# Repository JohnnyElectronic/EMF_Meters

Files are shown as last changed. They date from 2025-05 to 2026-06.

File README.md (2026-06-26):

# EMF Meter Replicas - Supernatural TV Series

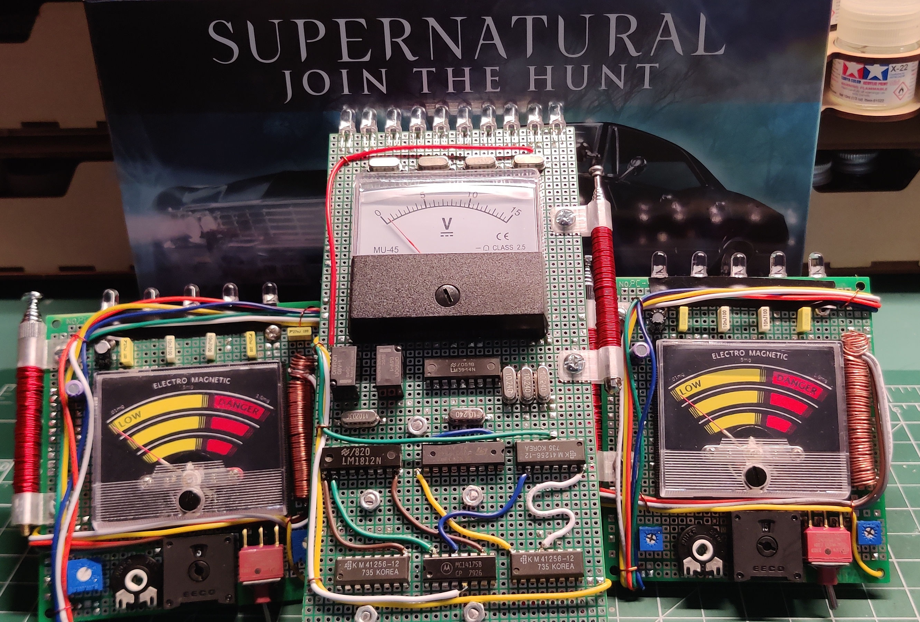
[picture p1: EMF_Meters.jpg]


## EMF Meters

- [Sam and Deans Classic EMF Meter](EMF_Meter_Replica/)
- [Olivia's 10 LED EMF Meter](10_LED_EMF_Meter_Replica/)

These meters are replicas of the ones seen in the Supernatural TV series.

* Sam and Deans Classic EMF Meter
This is the classic meter seen in many of the Supernatural episodes. It can be configured with 4 or 5 capacitors at the top, supports a variety of variable resistors and 9v or AA batteries.
This meter is a functional EMF meter and can detect Electric and Magnetic fields. It also has a test button to create EMF events any time.

* Olivia's 10 LED EMF Meter
This meter was only shown in one episode of the series but was a very standout meter. This is a prop only version with no EMF detection abilities. It was hand crafted on perfboard using point to point solder connections.
This is truly a one-of-a-kind meter. The meter has a test button similar to the other EMF meter for creating custom EMF events and also has 3 pre-programmed event sequences. These pre-programmed sequences can be added to or changed by reprogramming the ATtiny85 code.

> [!NOTE]
> [See My YouTube Channel for videos on assembly and operation of these meters](https://www.youtube.com/@Johnny_Electronic)

## Purchasing

[Visit my Etsy Store](https://johnnyelectronic.etsy.com)



## Licensing

This work is licensed under Creative Commons Attribution-ShareAlike 4.0 International. 
To view a copy of this license, visit [https://creativecommons.org/licenses/by-sa/4.0/](https://creativecommons.org/licenses/by-sa/4.0/)

Distributed as-is; no warranty is given.

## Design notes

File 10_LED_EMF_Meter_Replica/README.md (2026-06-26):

# 10 LED EMF Meter Replica - Olivia's Meter

- [Original perfboard (r1)](r1/)
- [New Updated Version on custom PCB (r2)](r2/)

Here is the documentation and support files for the Supernatural 10 LED EMF Meter Replica that Olivia used in season 4 episode 2. 
To assemble this circuit board you must be comfortable working with and soldering electronic parts.

This meter was only shown in one episode of the series but was a very standout meter. This is a prop only version with no EMF detection abilities. 
This is truly a unique meter. The meter has a test button similar to the other EMF meter for creating custom EMF events and also has 9 pre-programmed event sequences. 
These pre-programmed sequences can be added to or changed by reprogramming the ATtiny code.

An ATTiny is used to control the DFPlayer sound board and the analog meter deflection.
Programming is done through either a ICSP or UPDI programming interface depending on version. 

Check out the documents folder for more details.

## Journal Pages Now Available!
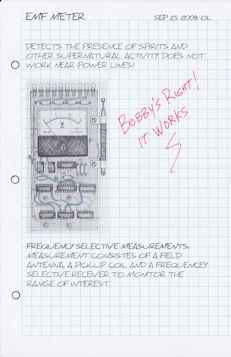
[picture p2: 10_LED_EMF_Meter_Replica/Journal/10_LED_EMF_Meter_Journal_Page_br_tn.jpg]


## Purchasing
[Visit my Etsy Store](https://johnnyelectronic.etsy.com)



## Directories

### Journal
-[Journal](Journal/)

### Version r1

-[Schematics](r1/schematics/)

-[Documents](r1/doc/)

-[Images](r1/img/)

-[Source code](r1/src/)

-[3D files](r1/3D/)

-[MP3 files](../EMF_Meter_Replica/mp3/)

### Version r2

-[Schematics](r2/schematics/)

-[Documents](r2/doc/)

-[Images](r2/img/)

-[Source code](r2/src/)

-[3D files](r1/3D/)

-[MP3 files](../EMF_Meter_Replica/mp3/)

### DFPlayer Files
-[DFPlayer](../DFPlayer/)

## Licensing

This work is licensed under Creative Commons Attribution-ShareAlike 4.0 International. 
To view a copy of this license, visit [https://creativecommons.org/licenses/by-sa/4.0/](https://creativecommons.org/licenses/by-sa/4.0/)

Distributed as-is; no warranty is given.

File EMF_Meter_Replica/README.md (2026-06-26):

# EMF Meter Replica - Supernatural TV Series



- [EMF Meter Replica (r1)](r1/)
- [EMF Meter Replica (r2) - Updated Version!](r2/)

Here is the documentation and support files for building and using the Supernatural EMF Meter Replica. 
To assemble this circuit board you must be comfortable working with and soldering electronic parts.
A full assembly and usage guide is available in the "doc" folder as well as a 2 part video series is 
available on YouTube.

## Technical Details

* Dimensions: 86 mm (3.46") x 95 mm (3.74") 
* Options for 9v or AA batteries
* 5 LEDS driven by an LM3914 (Jumper Option for DOT/BAR Mode)
* ATtiny85 controller
* DFPlayer module for audio
* Supports 3326,3362, or 3386 F and P series blue potentiometers
* Supports PT10 or PT15 black potentiometer
* Optional 5th yellow capacitor
* Uses a functional EECO switch to select the gain for the E-Field detector and can support a number of different EECO switches. Specifically, EECO 2700 series -02, -19, -31, -33, -41, -44 will work as is and others can be adapted to work. The PCB footprint supports 6 and 12 pin switches.
* Flexible wiring options.

This is a functional EMF meter that can detect both Electric and Magnetic fields. 
It can also be built as a simple prop by not populating the analog components. 
The meter was designed to replicate a variety of the meter configurations used in the TV series.

An ATTiny85 is used to control the DFPlayer sound board. 
Programming for the ATTiny85 can be accomplished using an In-Circuit Serial Programming (ICSP) port to program the part on the board. 
I also have available a soft touch programming cable for programming this part. 

Check out the documents folder for more details.

> [!NOTE]
> [See My YouTube Channel for examples on programming ATTiny parts using a softtouch cable](https://www.youtube.com/@Johnny_Electronic/playlists)

## Journal Pages Now Available!
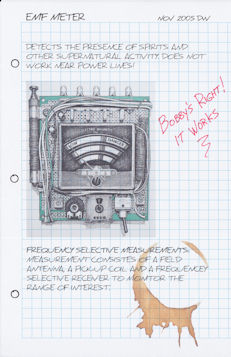
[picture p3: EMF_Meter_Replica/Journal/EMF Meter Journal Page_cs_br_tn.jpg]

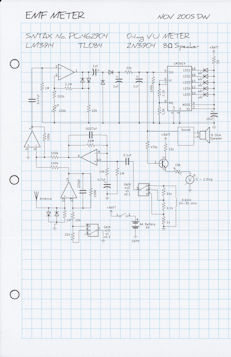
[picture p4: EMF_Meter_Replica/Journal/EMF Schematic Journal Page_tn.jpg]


## Purchasing
[Visit my Etsy Store](https://johnnyelectronic.etsy.com)



## Directories

### Journal Pages
-[Journal Pages](Journal/)

### Version r1

-[Schematics](r1/schematics/)

-[Documents](r1/doc/)

-[Images](r1/img/)

-[Source code](src/)

-[3D files](3D/)

-[MP3 files](mp3/)

### Version r2

-[Schematics](r2/schematics/)

-[Documents](r2/doc/)

-[Images](r2/img/)

-[Source code](src/)

-[3D files](3D/)

-[MP3 files](mp3/)

### DFPlayer Files
-[DFPlayer](../DFPlayer/)

## Licensing

This work is licensed under Creative Commons Attribution-ShareAlike 4.0 International. 
To view a copy of this license, visit [https://creativecommons.org/licenses/by-sa/4.0/](https://creativecommons.org/licenses/by-sa/4.0/)

Distributed as-is; no warranty is given.

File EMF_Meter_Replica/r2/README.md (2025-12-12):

# EMF Meter Replica (r2) - Updated Version!

**Blank PCB**

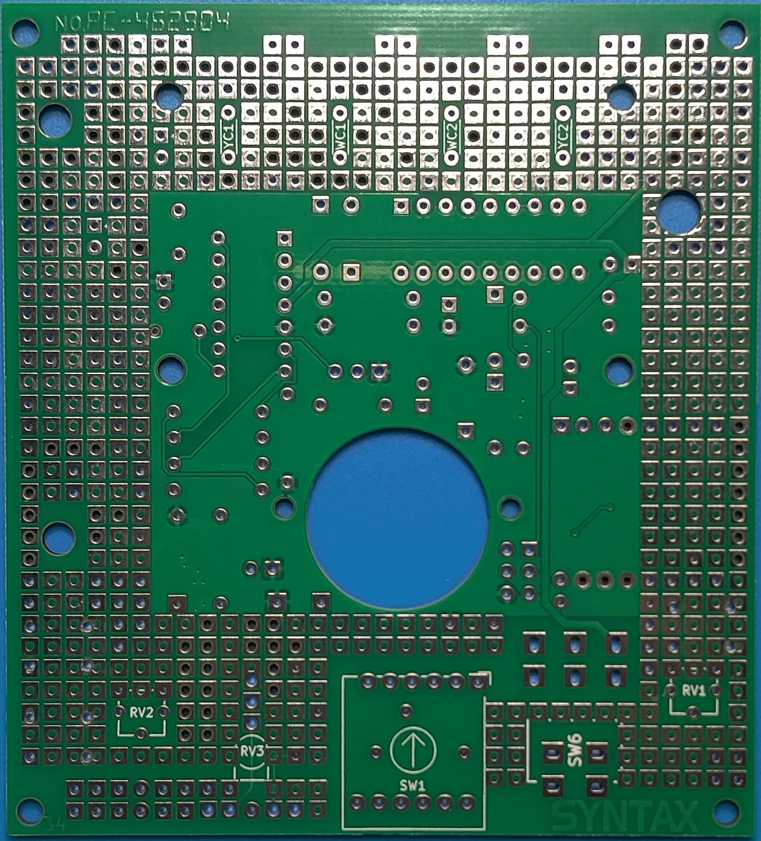
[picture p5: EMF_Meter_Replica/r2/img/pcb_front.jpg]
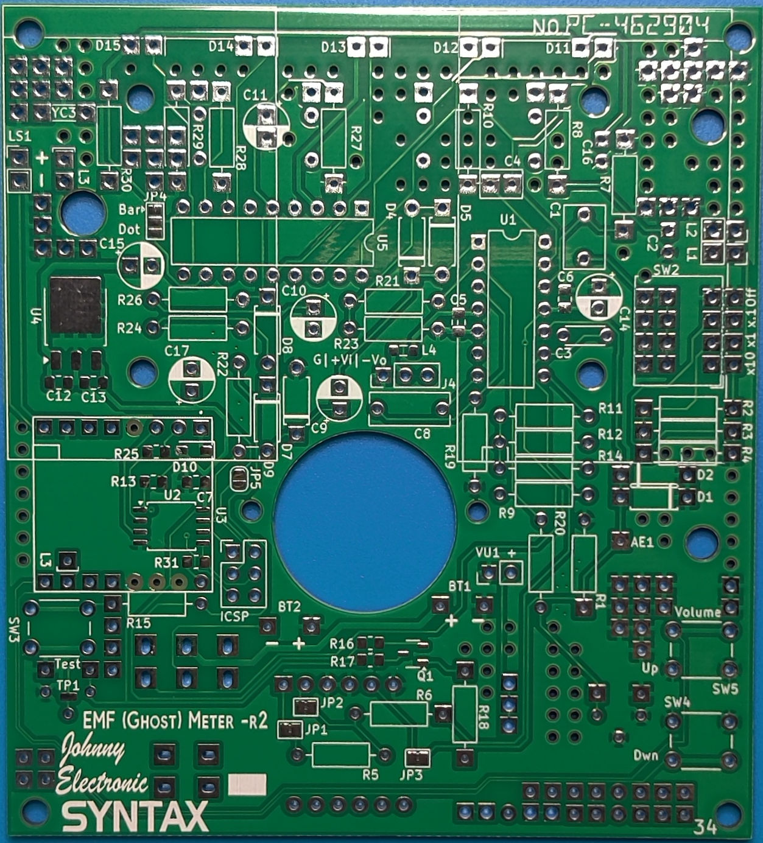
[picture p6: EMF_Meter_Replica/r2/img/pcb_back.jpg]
  

**Example of Assembled EMF Meter**

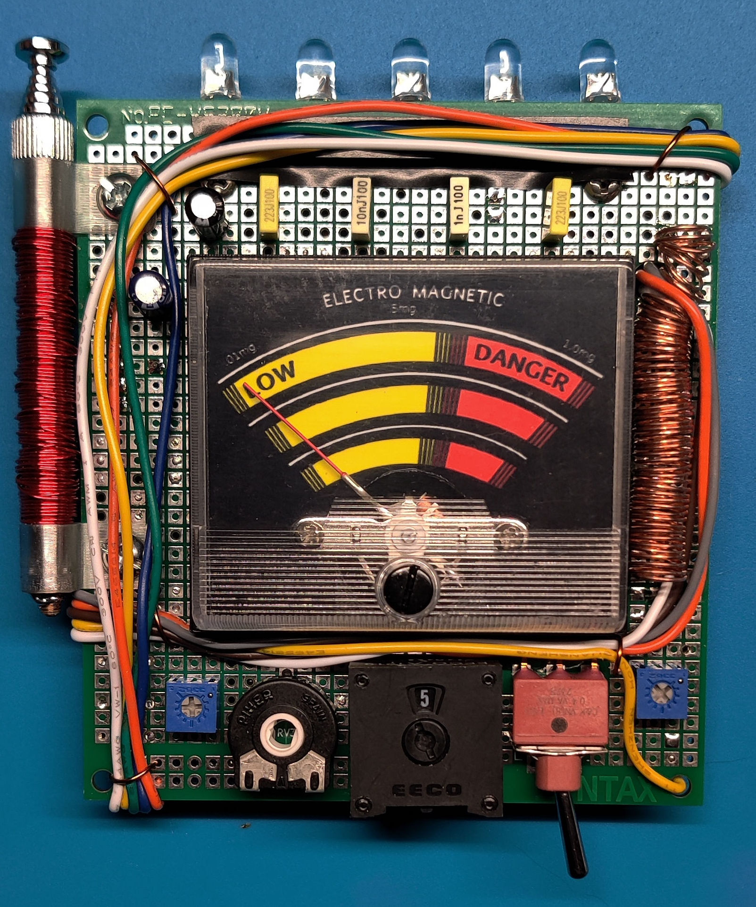
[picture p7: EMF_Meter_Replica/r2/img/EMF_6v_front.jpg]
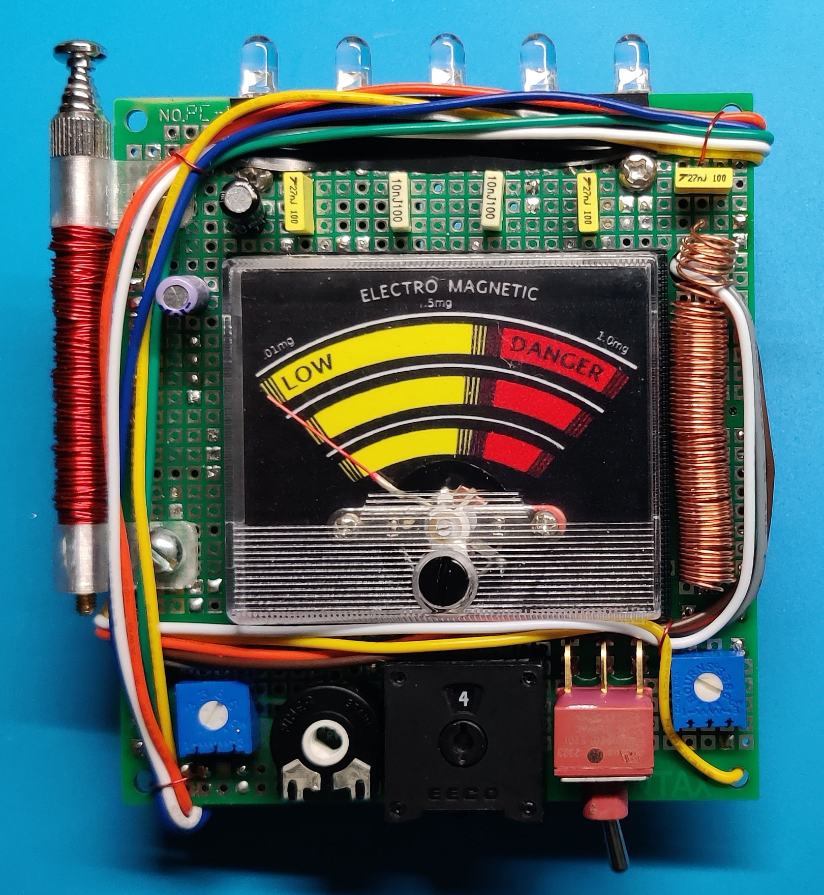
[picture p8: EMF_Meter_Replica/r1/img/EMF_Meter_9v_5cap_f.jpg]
  

Here is the documentation and support files for building and using the Supernatural EMF Meter Replica. 
To assemble this circuit board you must be comfortable working with and soldering electronic parts.
A full assembly and usage guide is available in the "doc" folder as well as a 2 part video series.

## Technical Details

* Dimensions: 86 mm (3.46") x 95 mm (3.74") 
* Options for 9v or AA batteries
* 5 LEDS driven by an LM3914 (Jumper Option for DOT/BAR Mode)
* ATtiny85 controller
* DFPlayer module for audio
* Supports 3326,3362, or 3386 F and P series blue potentiometers
* Supports PT10 or PT15 black potentiometer
* Optional 5th yellow capacitor
* Uses a functional EECO switch to select the gain for the E-Field detector and can support a number of different EECO switches. Specifically, EECO 2700 series -02, -19, -31, -33, -41, -44 will work as is and others can be adapted to work. The PCB footprint supports 6 and 12 pin switches.
* Flexible wiring options.

This is a functional EMF meter that can detect both Electric and Magnetic fields. 
It can also be built as a simple prop by not populating the analog components. 
The meter was designed to replicate a variety of the meter configurations used in the TV series.

An ATTiny85 is used to control the DFPlayer sound board. 
Programming for the ATTiny85 can also be accomplished using an In-Circuit Serial Programming (ICSP) port to program the mounted part on the board. 
I also have available a soft touch programming cable for programming this part. 

Check out the documents folder for more details.

> [!NOTE]
> [See My YouTube Channel for examples on programming ATTiny parts using a softtouch cable](https://www.youtube.com/@Johnny_Electronic/playlists)

## Purchasing
[Visit my Tindie Store](https://www.tindie.com/stores/johnnyelectronic/)



## Directories

-[Schematics](schematics/)

-[Documents](doc/)

-[Images](img/)

-[Source code](../src/)

-[3D files](../3D/)

-[MP3 files](../mp3/)

## Licensing

This work is licensed under Creative Commons Attribution-ShareAlike 4.0 International. 
To view a copy of this license, visit [https://creativecommons.org/licenses/by-sa/4.0/](https://creativecommons.org/licenses/by-sa/4.0/)

Distributed as-is; no warranty is given.

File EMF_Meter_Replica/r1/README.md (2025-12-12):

# EMF Meter Replica (r1) - Discontinued

**Blank PCB**

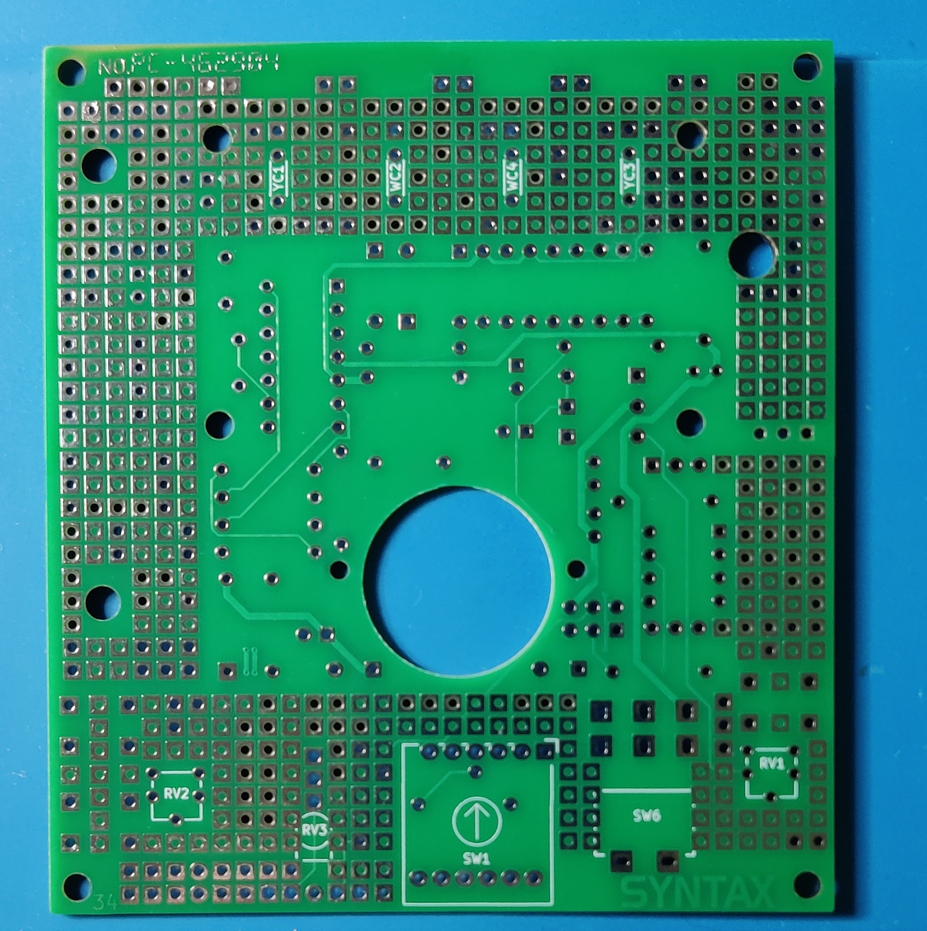
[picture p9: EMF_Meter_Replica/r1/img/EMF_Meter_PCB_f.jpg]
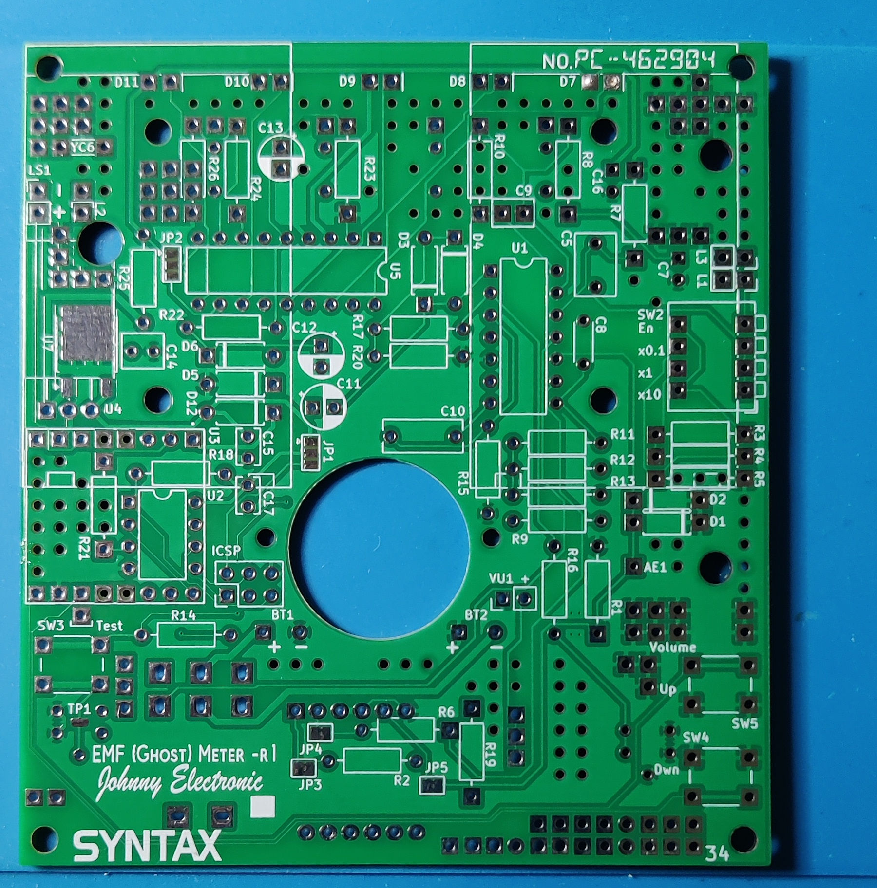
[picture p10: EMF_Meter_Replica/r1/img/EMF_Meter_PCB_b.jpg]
  

**Example of Assembled EMF Meter**

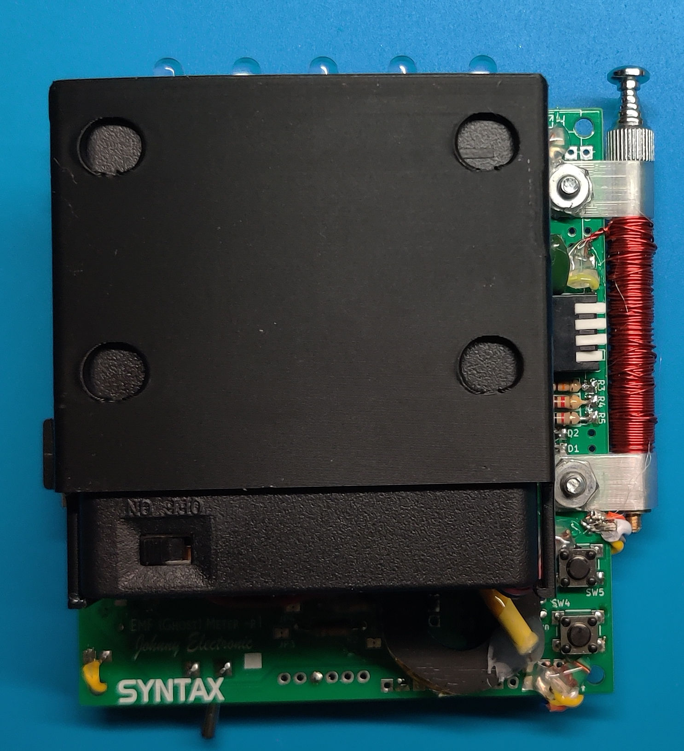
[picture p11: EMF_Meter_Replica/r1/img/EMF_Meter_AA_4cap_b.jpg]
  

Here is the documentation and support files for building and using the Supernatural EMF Meter Replica. 
To assemble this circuit board you must be comfortable working with and soldering electronic parts.
A full assembly and usage guide is available in the "doc" folder as well as a 2 part video series.

## Technical Details

* Dimensions: 86 mm (3.46") x 95 mm (3.74") 
* Options for 9v or AA batteries
* 5 LEDS driven by an LM3914 (Jumper Option for DOT/BAR Mode)
* ATtiny85 controller
* DFPlayer module for audio
* Supports 3326,3362, or 3386 F and P series blue potentiometers
* Supports PT10 or PT15 black potentiometer
* Optional 5th yellow capacitor
* Uses a functional EECO switch to select the gain for the E-Field detector and can support a number of different EECO switches. Specifically, EECO 2700 series -02, -19, -31, -33, -41, -44 will work as is and others can be adapted to work. The PCB footprint supports 6 and 12 pin switches.
* Flexible wiring options.

This is a functional EMF meter that can detect both Electric and Magnetic fields. 
It can also be built as a simple prop by not populating the analog components. 
The meter was designed to replicate a variety of the meter configurations used in the TV series.

An ATTiny85 is used to control the DFPlayer sound board. 
Programming for the ATTiny85 can be done before mounting and can also be accomplished using an In-Circuit Serial Programming (ICSP) port to program the mounted part on the board. 
There is a jumper option (JP1) to select either the main board power or to use the ICSP port for programming power. I also have available a soft touch programming cable for programming this part. 

Check out the documents folder for more details.

> [!NOTE]
> [See My YouTube Channel for examples on programming ATTiny parts using a softtouch cable](https://www.youtube.com/@Johnny_Electronic/playlists)

## Purchasing
[Visit my Tindie Store](https://www.tindie.com/stores/johnnyelectronic/)



## Directories

-[Schematics](schematics/)

-[Documents](doc/)

-[Images](img/)

-[Source code](../src/)

-[3D files](../3D/)

-[MP3 files](../mp3/)

## Licensing

This work is licensed under Creative Commons Attribution-ShareAlike 4.0 International. 
To view a copy of this license, visit [https://creativecommons.org/licenses/by-sa/4.0/](https://creativecommons.org/licenses/by-sa/4.0/)

Distributed as-is; no warranty is given.

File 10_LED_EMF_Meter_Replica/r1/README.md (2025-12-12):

# 10 LED EMF Meter Replica - Olivia's Meter (r1)

**Blank PCB**

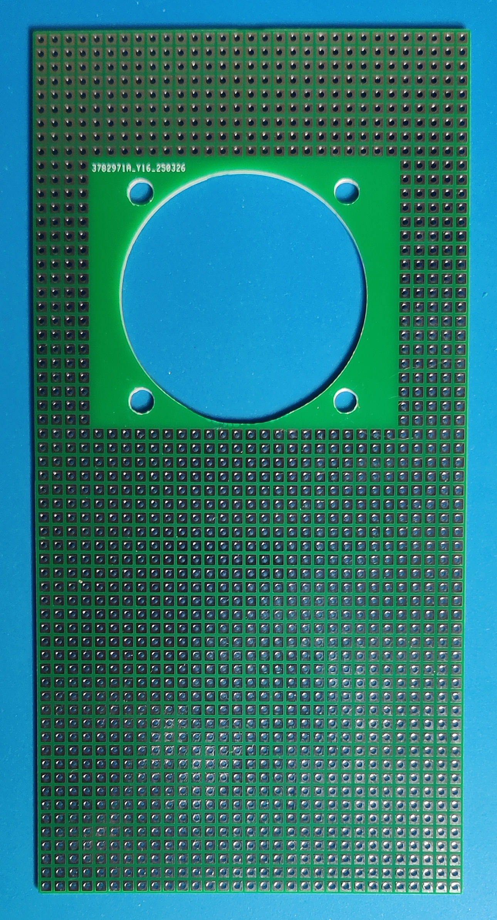
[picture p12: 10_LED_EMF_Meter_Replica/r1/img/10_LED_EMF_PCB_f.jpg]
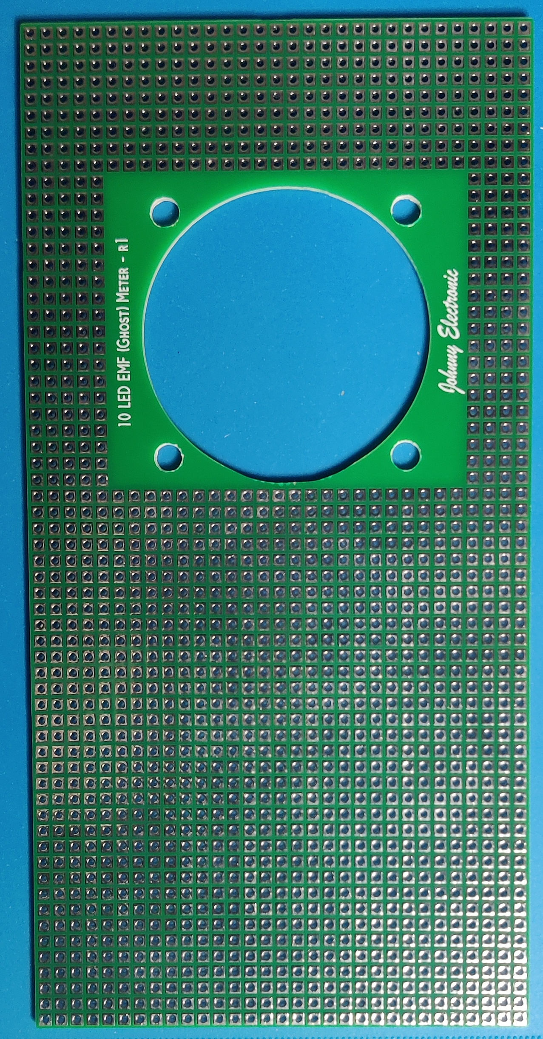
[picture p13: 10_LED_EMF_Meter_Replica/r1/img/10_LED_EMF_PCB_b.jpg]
  

**Example of Assembled EMF Meter**

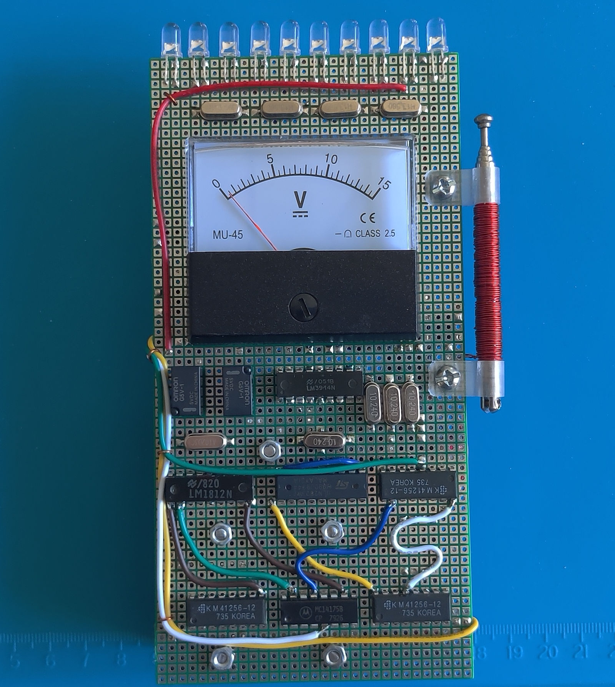
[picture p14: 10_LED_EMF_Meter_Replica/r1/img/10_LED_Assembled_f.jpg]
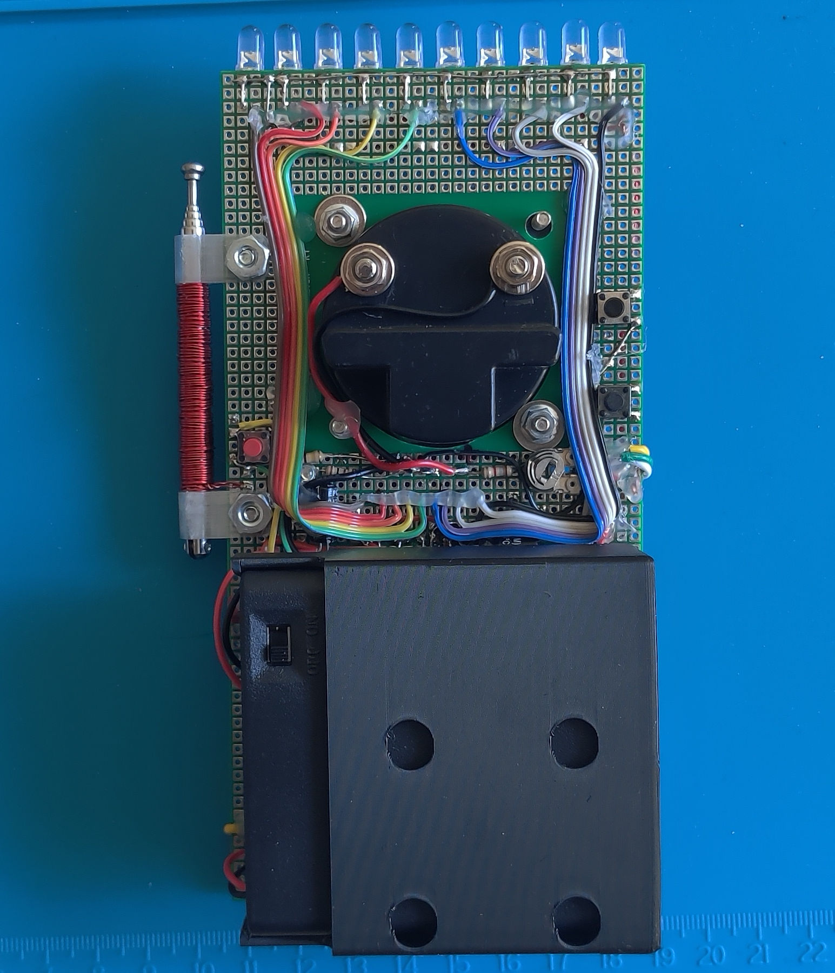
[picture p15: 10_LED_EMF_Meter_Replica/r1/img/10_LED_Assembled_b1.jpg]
  

Here is the documentation and support files for the Supernatural 10 LED EMF Meter Replica that Olivia used in season 4 episode 2. 
To assemble this circuit board you must be comfortable working with and soldering electronic parts.
A partial build video is available on my YouTube site. This meter is built on a perfboard so assembly is at the discreation of the hunter (Ah, builder).
A schematic is available along with a Bill of Materials (BOM). 

## Technical Details

* Dimensions: 79 mm x 158 mm 
* Uses 4 AA batteries
* 10 LEDS driven by an LM3914 (Set to BAR mode)
* ATtiny85 controller
* DFPlayer module for audio

This meter was only shown in one episode of the series but was a very standout meter. This is a prop only version with no EMF detection abilities. It was hand crafted on perfboard using point to point solder connections.
This is truly a one-of-a-kind meter. The meter has a test button similar to the other EMF meter for creating custom EMF events and also has 3 pre-programmed event sequences. 
These pre-programmed sequences can be added to or changed by reprogramming the ATtiny85 code.

An ATTiny85 is used to control the DFPlayer sound board and the analog meter deflection. 
The ATTiny85 is socketed and can be reprogrammed if needed. 

Check out the documents folder for more details.

## Purchasing
[Visit my Tindie Store](https://www.tindie.com/stores/johnnyelectronic/)



## Directories

-[Schematics](schematics/)

-[Documents](doc/)

-[Images](img/)

-[Source code](src/)

-[3D files](3D/)

## Licensing

This work is licensed under Creative Commons Attribution-ShareAlike 4.0 International. 
To view a copy of this license, visit [https://creativecommons.org/licenses/by-sa/4.0/](https://creativecommons.org/licenses/by-sa/4.0/)

Distributed as-is; no warranty is given.

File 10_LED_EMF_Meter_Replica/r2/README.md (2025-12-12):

# 10 LED EMF Meter Replica - Olivia's Meter (r2)

### Updated version ###

**Blank PCB**

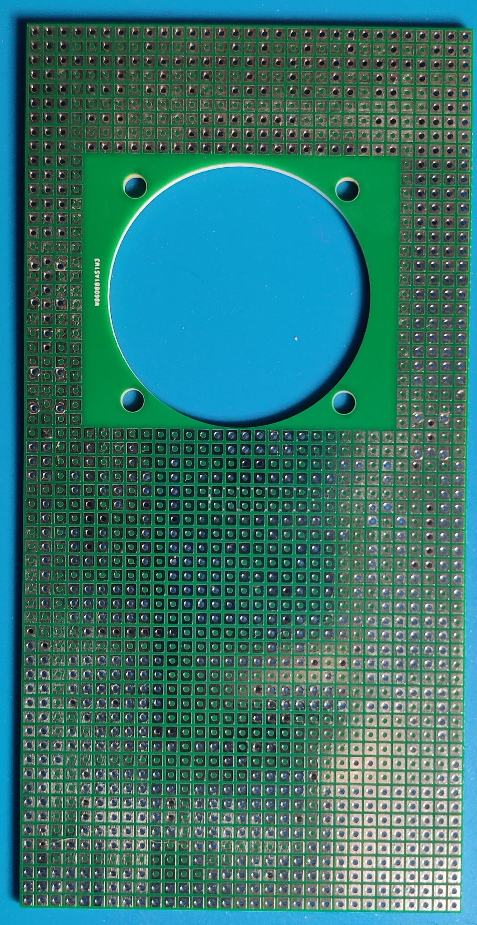
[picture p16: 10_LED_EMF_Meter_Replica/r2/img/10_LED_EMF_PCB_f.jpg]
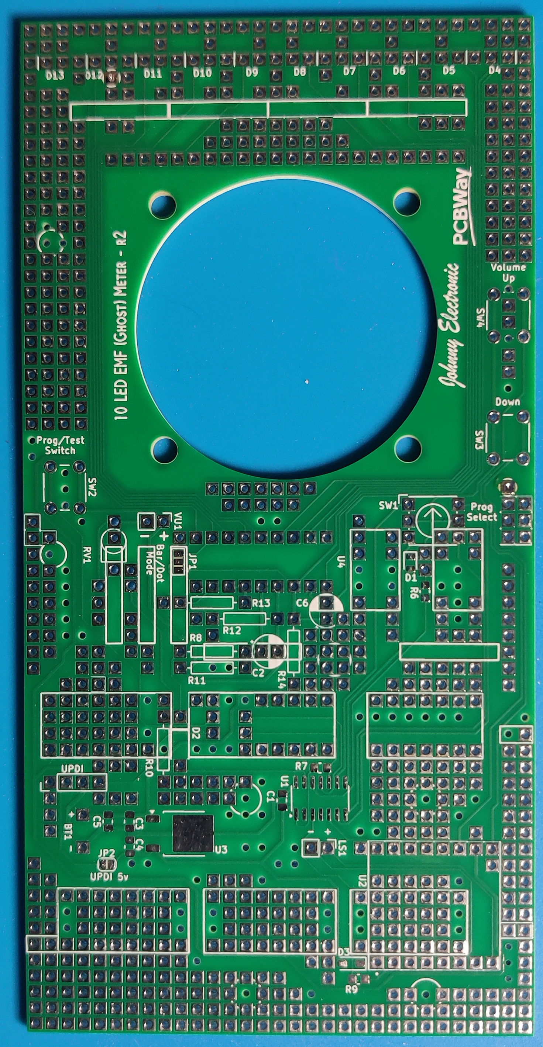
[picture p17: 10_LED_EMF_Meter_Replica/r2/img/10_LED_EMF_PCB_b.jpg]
  

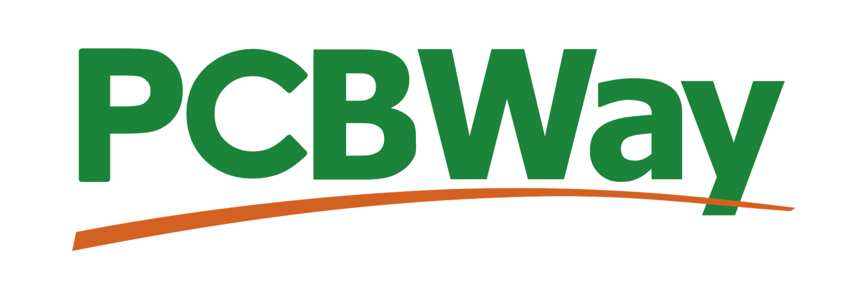
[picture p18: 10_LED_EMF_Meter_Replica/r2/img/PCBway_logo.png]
**PCB Made By**

**Example of Assembled EMF Meter**

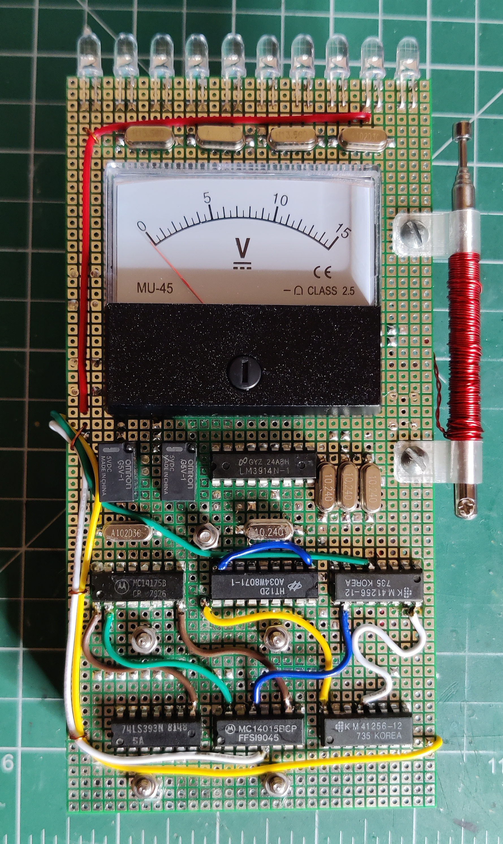
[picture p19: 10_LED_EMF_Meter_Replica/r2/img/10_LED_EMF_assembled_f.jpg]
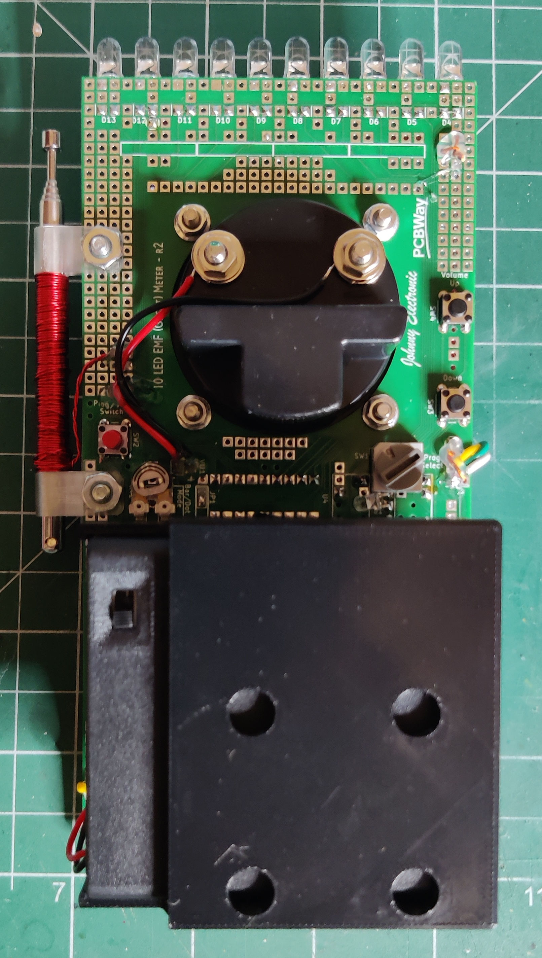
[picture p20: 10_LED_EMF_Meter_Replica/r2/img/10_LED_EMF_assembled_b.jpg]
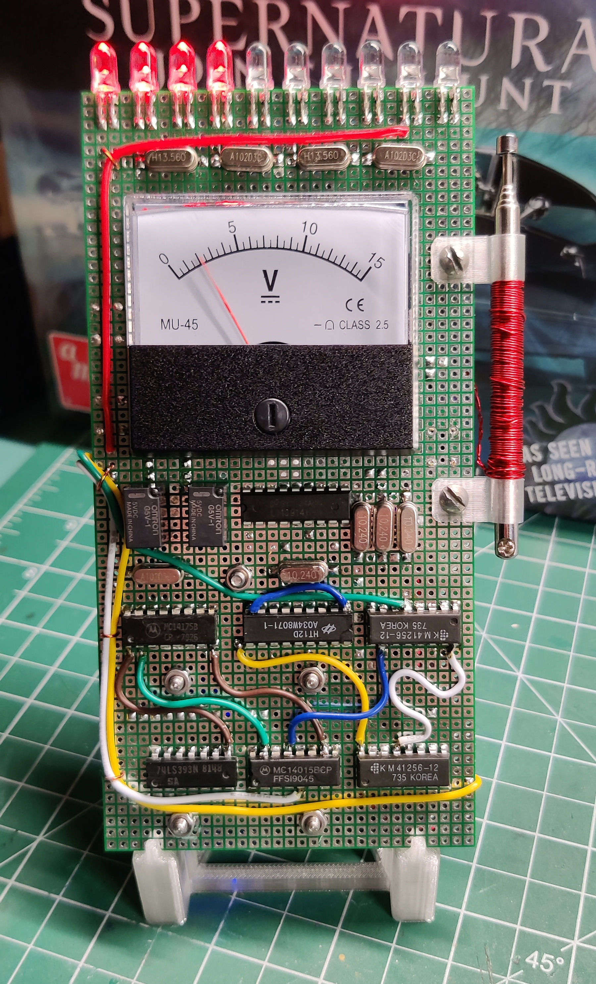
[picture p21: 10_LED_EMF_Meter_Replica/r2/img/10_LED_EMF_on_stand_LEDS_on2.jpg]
    

Here is the documentation and support files for the Supernatural 10 LED EMF Meter Replica that Olivia used in season 4 episode 2. 
To assemble this circuit board you must be comfortable working with and soldering electronic parts.
A build video is available on my YouTube site. This meter uses through hole and surface mounted parts. The smallest SMT will be a 0805 package.
A schematic is available along with a Bill of Materials (BOM). 

## Technical Details

* Dimensions: 79 mm x 158 mm 
* Uses 4 AA batteries
* 10 LEDS driven by an LM3914N (Set to BAR mode)
* ATTiny1604 controller
* DFPlayer module for audio
* 9 Pre-Programmed EMF sequences

This meter was only shown in one episode of the series but was a very standout meter. This is a prop only version with no EMF detection abilities. 
This is truly a unique meter. The meter has a test button similar to the other EMF meter for creating custom EMF events and also has 9 pre-programmed event sequences.
The pre-programmed sequences can be selected using a rotary switch and then a quick press of the Program/Test button to start the sequence. Using the 0 position each button
press will rotate to the next programmed sequence. These pre-programmed sequences can be added to or changed by reprogramming the ATtiny code.

An ATTiny1604 is used to control the DFPlayer sound board and the VU/LED meter deflection. 
The ATTiny1604 can be reprogrammed using the UPDI port. 

Check out the documents folder for more details.

## Purchasing
[Visit my Tindie Store](https://www.tindie.com/stores/johnnyelectronic/)



## Directories

-[Schematics](schematics/)

-[Documents](doc/)

-[Images](img/)

-[Source code](src/)

-[3D files](../r1/3D/)

-[MP3 files](../../EMF_Meter_Replica/mp3/)

## Licensing

This work is licensed under Creative Commons Attribution-ShareAlike 4.0 International. 
To view a copy of this license, visit [https://creativecommons.org/licenses/by-sa/4.0/](https://creativecommons.org/licenses/by-sa/4.0/)

Distributed as-is; no warranty is given.

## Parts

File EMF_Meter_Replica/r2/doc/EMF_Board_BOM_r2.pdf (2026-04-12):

### Functional EMF Meter -r2 BOM

Reference | Description | Value | Quantity | Dat sheet or Part Link

AE1

Antenna 3” – 8 5/8”, 5 Segment, Dia. 5mm (.198”)
or ATT 5000 Cordless phone antenna | Ant 3", 5mm | 0

AliExpress. 17/25cm 5 Section Metal Full-Channel Am Fm Radio Antenna Telescopic Antenna Rotating Antenna Aerial M2.5 https://www.aliexpress.us/item/3256806492066394.html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 21US%212927003445%21X&curPageLogUid=uOVDvnEgydBL&utparam-url=scene%3Asearch%7Cquery_from%3A

eBay for the ATT

+ Red Enamel 26 AWG Wire Wrap
AE1 Option | ATT 5000 Cordless phone antenna | 6mm Dia 3" antenna | 1 eBay as low as $3.5 each
BT1 | 6v Battery Pack - 6V Option | 4 AA Batteries | 1 For 6V supply BT1, BT1 3D, Buck1 are required.
| | | Aliexpress: https://www.aliexpress.us/w/wholesale-4-Slots-AA-Battery-Holder.html?spm=a2g0o.productlist.search.0
BT1 3D | 6v Battery Pack Mount, 3D printed | AA 3D Holder | 1 For 6V supply BT1, 3D printed batterypack holder. AAx4 battery pack required
BUCK1 | 6V buck converter | DD0315NA | 1 https://www.aliexpress.us/item/2251832636713190.html
BT1,BT2 | 9v Battery Clip and Holder - 9V Option | 3D Printed | 0 For 9V supply BT1, BT2, 9V batteries with clips + 3D printed 9V batery Holder, 2 each required
YC1,YC2,YC3 | Yellow .022uf Cosmetic Capacitor (22n) | Y .022uf Cosmetic | 3 All Electronics, Yellow Metallized polyester film radial capacitors. 22n or 22 nf desired. .022uf
| | | AliExpress
WC2,WC2 | White .001uf Cosmetic Capacitor (10n) | W .001uf Cosmetic | 2 All Electronics, White Metallized polyester film radial capacitors. Marking 10n desired, .001uf
| | | AliExpress
C1 | Mylar Capacitor | 0.1uf | 1 MLCC substitute or Jameco / AliExpress for Mylar
C2 | Electrolytic Capacitor - Blue Sleeve | 4.7uf | 1 Mouser/Digikey
C3 | Ceramic Disk Capacitor | 220pf | 1 Mouser/Digikey
C4 | Mylar/MLCC Capacitor | .0027uf | 1 AliExpress/Mouser
C8 | Mylar/MLCC Capacitor | .047uf | 1 Jameco, AliExpress, Mouser/Digikey
C9,C10,C11 | Electrolytic Capacitor | 1uf | 3 Mouser/Digikey
C17 | Electrolytic Capacitor - Optional based on 5v regulator | 1uf | 1 Mouser/Digikey
C12,C13 | Ceramic Capacitor-0805 SMD, Based on Regulator | 0.1-0.33uf | 1 Mouser/Digikey, 0805 Package
C5,C6,C7 | Ceramic Capacitor-0805 SMD | 0.1uf | 3 Mouser/Digikey, 0805 Package
C14 | Electrolytic Capacitor - Optional, used with -6v BUCK1 | 220uf | 1 Mouser/Digikey, 220uf/10v
C15 | Electrolytic Capacitor | 10uf | 1 Mouser/Digikey
C16 | Electrolytic Capacitor - Black Sleeve | 10uf | 1 Mouser/Digikey
D1, D2, D4, D5, D7, D8, D9 | Signal Diode | 1N914 | 7 Mouser/Digikey
D11, D12, D13, D14, D15 | Red LED | Ultra Bright Red, 5MM | 5 Mouser, Lighthouse LED, AliExpress
D10 | Rectifier Diode, SMD | SL1A | 1 IN4001 equivalent, SL1A, Any source, SMD, SOD-123 package
L1 | EMF Pickup coil | 3D Printed | 1 32 gauge. 36 AWG Preferred 32g 0.11 per ft @ 120'
L2 | Cosmetic Antenna Coil Left Side, Optional EMF connection | Hand Made | 1 26 AWG red enameled, two layer wrap around telescopic antenna
L3 | Cosmetic Coil Right Side | Hand Made | 1 22AWG 0.6438mm 0.0253”, Copper Wire 0.65mm
L4 | 33uH Inductor, SMD 0805 | 33uH | 1 Mouser/Digikey, 33uH 0805 Package
LS1 | Speaker 20x30x4.6mm, 8 ohm, 1.5 Watt, Oval | 20x30mm 1-2Watt | 1 AliExpress. https://www.aliexpress.us/w/wholesale-Speaker-20x30mm.html?spm=a2g0o.productlist.search.0
Q1 | 2N3904/CMPT3019 or Equiv, SMD SOT-23 | CMPT3019 | 1 Mouser/Digikey
R1, R19, R7 | 1/4w Resistor | 1M | 3 Any source
R26, R5 | 1/4w Resistor | 22k | 2 Any source
R2 | 1/4w Resistor | 91k | 1 Any source
R3 | 1/4w Resistor | 9.1k | 1 Any source
R4 | 1/4w Resistor | 1k | 1 Any source
R23, R6, R8 | 1/4w Resistor | 10k | 3 Any source
R13 | 1/8w SMD Resistor, 0805 | 10k | 1 Any source
R11, R12, R14, R20, R27, R9 1/4w Resistor | 100k | 6 Any source
R10 | 1/4w Resistor | 10M | 1 Any source
R15 | 1/4w Resistor | 100 | 1 Any source
R16 | 1/8w SMD Resistor, 0805 | 470k | 1 Any source
R22 | 1/4w Resistor | 3.3M | 1 Any source
R21 | 1/4w Resistor | 2.2M | 1 Any source
R17 | 1/8w SMD Resistor, 0805 | 15k | 1 Any source
R18 | 1/4w Resistor | 7.5k | 1 Any source
R24 | 1/4w Resistor | 47k | 1 Any source
R25, R31 | 1/8w SMD Resistor, 0805 | 1.8k | 2 Any source
R28 | 1/4w Resistor | 1.2k | 1 Any source
R30 | 1/4w Resistor | 33 | 1 Any source
R29 | 1/4w Resistor | 1.5k | 1 Any source
RV1,RV2 | Variable resistor. 3326/3362/3386 F or P series | 100k | 2 Mouser Electronics, https://www.mouser.com/ProductDetail/Bourns/3386H-1-104LF?qs=m2uG%2FFdTAPVxro77x9HS0w%3D%3D
| | | Jameco https://www.jameco.com/z/3386P-1-104LF-JVP-Jameco-ValuePro-1-2-Watt-3-8-Square-Trimming-Potentiometer-100k-Ohm_43027.html ($0.99)
RV3 | 1k/5k ohm, Variable resistor (PT15 Series) | 5k | 1 PT15NV02-502A
| | | Included with VU meter or Jameco for PT15 Black Pot
SW1 | SW_Coded_EECO_2700 -31/33 | EECO 276133M | 1 eBay. A Variety of switches are supported.
SW2 | SW_DIP_x04, Piano or Rotary S-2151 | SW_DIP_x04 | 1 Digikey or Mouser, https://www.mouser.com/ProductDetail/CTS-Electronic-Components/195-4MS?qs=hDoPxpGr7ldwh3tetBscOg%3D%3D
| | | https://www.mouser.com/ProductDetail/Nidec-Components/S-2151?qs=XeJtXLiO41Q6vTgIJbo%2FGA%3D%3D
SW3,SW4,SW5 | SW_Push. 6x6x5mm SPST | Tactile Switches,6X6 | 3 Mouser, AliExpress

SW6

SW_SPDT AA Supply E101SD1ABE $16.62

| SW_DPDT 9v Supply E201MD1AV2BE $12.32-$15.46 | Toggle Switch | 1 Digikey/Mouser, C&K E201MD1AQE ($15.46) or E-Switch 100DP1T1B1M6QE ($4.35)
| | | https://www.mouser.com/ProductDetail/CK/E201MD1AQE?qs=c89up6qpALNEJs%2FyQ1km0A%3D%3D
| | | https://www.mouser.com/ProductDetail/E-Switch/100DP1T1B1M6QE?qs=wUXugUrL1qxY%252BYjsepFRcA%3D%3D
| | | https://www.mouser.com/ProductDetail/CK/E101SD1ABE?qs=V27O%2FkrGudytwoweDEvTYA%3D%3D
| | | 7mm MTS-202C3 AliExpress (Chrome casing $1.18)
U1 | TL084ACN | TL084 | 1 Mouser/Digikey
U2 | ATtiny85-20U, SOIC8 SMD | ATtiny85-20U | 1 Mouser/Digikey
U3 | DF Player PCB | DFR0299 | 1 AliExpress DFPlayer Mini, MP3-TF-16P (JL chip set, Blue LED Best. DFRobot works but some audio amp clicks $7-9)
U4 | 5v regulator (LDO), DPAK, SMD | TC1262-5 | 1 LF50CDT Regulator Minimum 500ma output. Mouser, w/ 9v source
| | | TC1262-5.0 Regulator LDO 500ma min, AA source
U5 | LM3914N | LM3914N | 1 AliExpress

VU1

Meter Element
Decibel Measurement on AC Voltage Range Analog Multimeter Tester for ACDC 1000V500m A/Voltmeter Ammeter Ohmmeter
Meter Volt
| Requires a 3D printed base | MF-110A | 1 AliExpress, https://www.aliexpress.us/w/wholesale-MF%2525252d110.html?spm=a2g0o.detail.search.0 (https://www.aliexpress.us/item/3256807924391371.html)
VU1_BASE | 3D Printed Base for MF-110 Meter element | | 1 Requires screws from MF-110A meter
Display Stand | 3D Printed, transparent | | 1
P-Clip | 6mm 3D printed, transparent | | 2 ATT antenna uses 6mm, Genric 3" antenna uses 5mm
MS-M3 | Mechanical screw, Battery Holder | M3 x 6mm | 8 AliExpress
MS-8 | Mechanical Threaded Standoff, Battery Holder | M3-10mm | 4 AliExpress
Misc Colored wire | Various wire routes, cosmetic only | 24 AWG | 1 Jameco, https://www.jameco.com/z/UL-1007-10CS-Jameco-ValuePro-24-AWG-10-Color-Stranded-Wire-Kit-Assortment_2187876.html
SD_CARD | Mico SD Card 1/4GB | 1 or 4GB | 1
EMF r2 PCB | PCB | | 1

### Approximate part cost $80.00

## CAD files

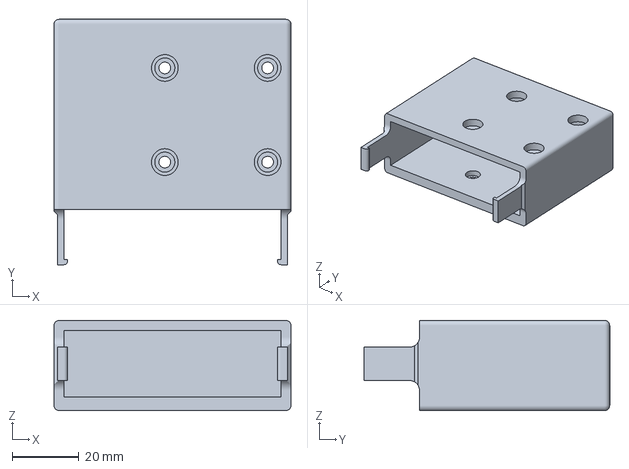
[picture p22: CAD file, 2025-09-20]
10_LED_EMF_Meter_Replica/r1/3D/AA_Battery_Pack_Holder_10_LED.3mf
71.0 x 73.6 x 27.0 mm

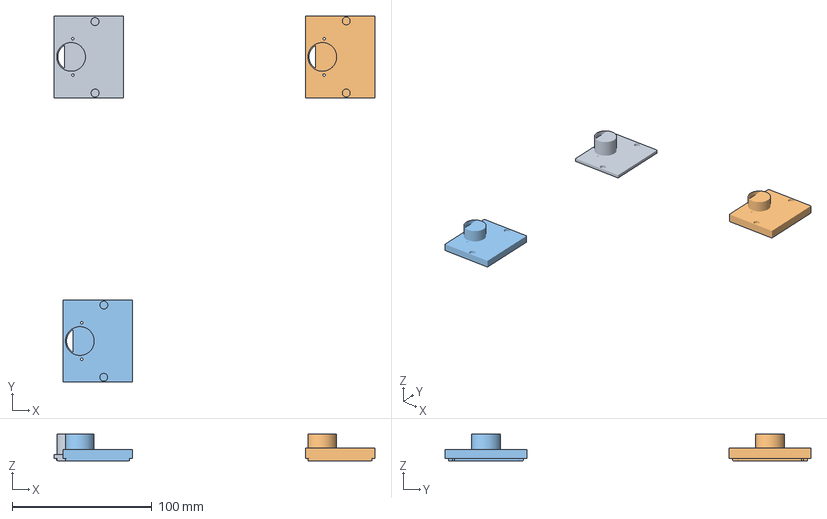
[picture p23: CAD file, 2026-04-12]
EMF_Meter_Replica/3D/EMF_Meter_Base_all versions.3mf
229.8 x 262.3 x 19.2 mm
Meter Base-7.6mm
Meter Base-6.6mm

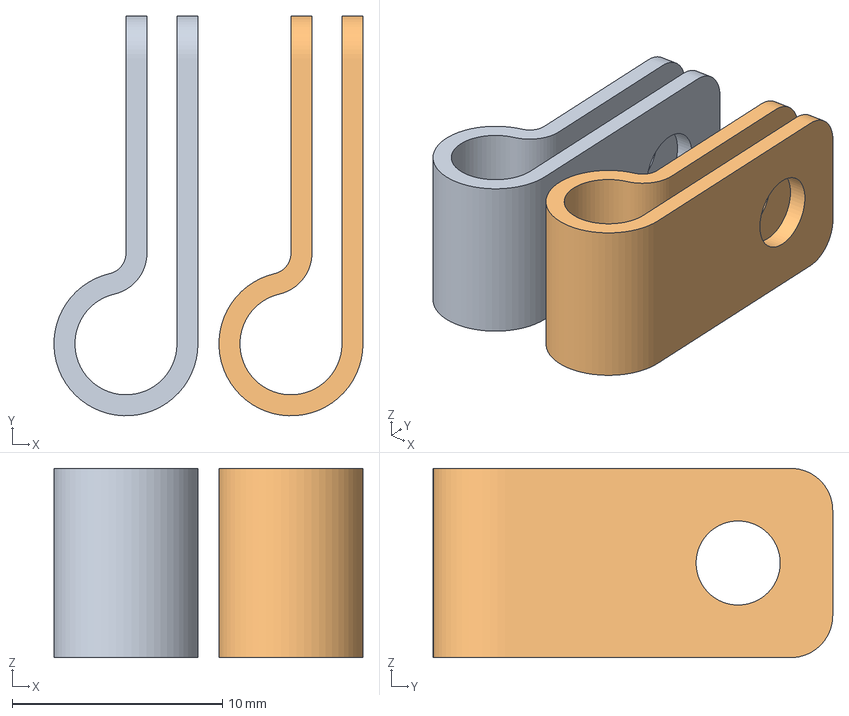
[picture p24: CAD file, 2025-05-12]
10_LED_EMF_Meter_Replica/r1/3D/EMF_P_Clip_5mm_dia.3mf
14.7 x 19.0 x 9.00 mm
P Clip x 2

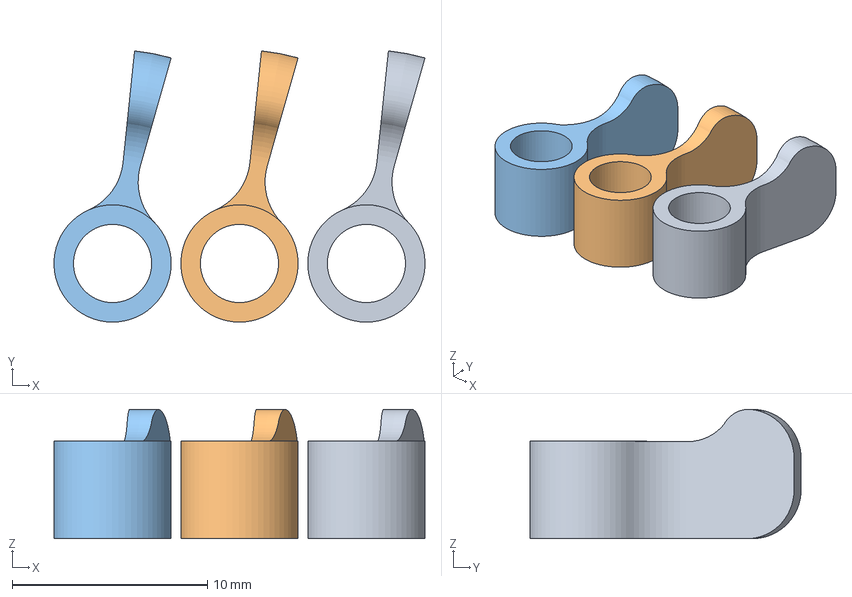
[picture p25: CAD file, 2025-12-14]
EMF_Meter_Replica/3D/Rotary Switch Lever.3mf
19.0 x 13.9 x 6.62 mm
Lever x 3

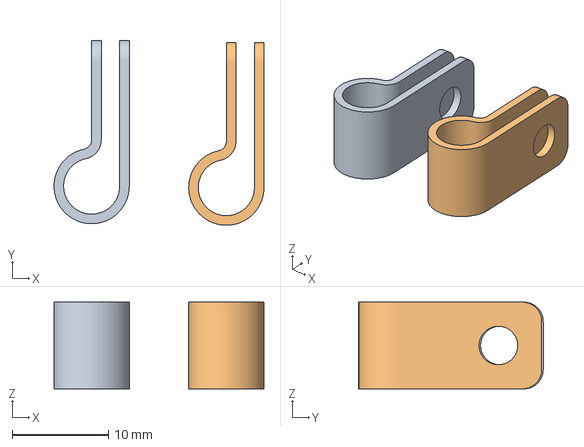
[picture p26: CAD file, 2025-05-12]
10_LED_EMF_Meter_Replica/r1/3D/EMF_P_Clip_6mm_dia.3mf
21.8 x 19.2 x 9.00 mm
P Clip x 2

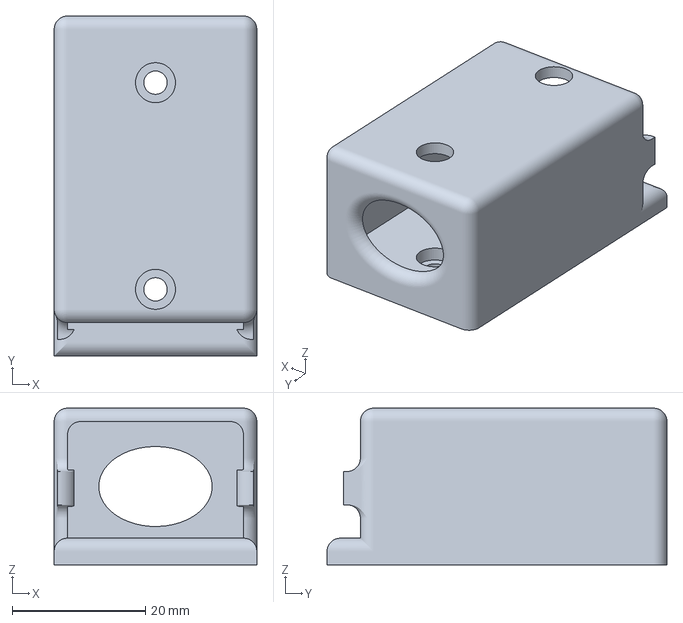
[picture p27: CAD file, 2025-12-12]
EMF_Meter_Replica/3D/9v_Battery_Holder.3mf
30.4 x 51.0 x 23.5 mm

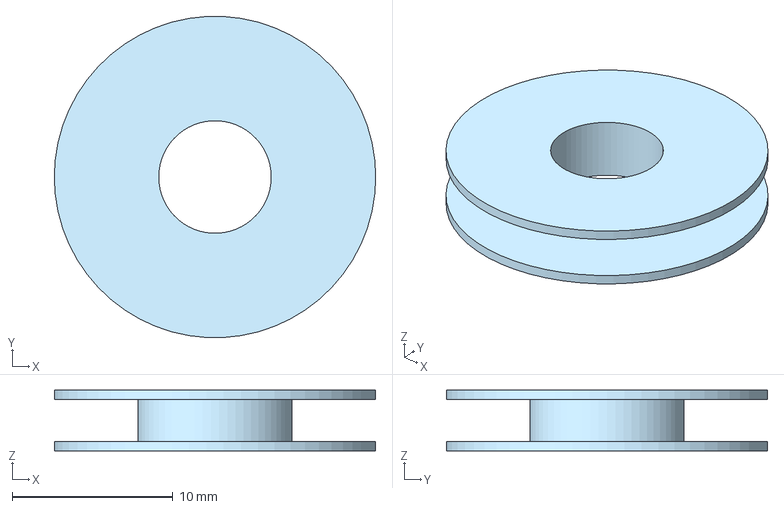
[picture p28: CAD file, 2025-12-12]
EMF_Meter_Replica/3D/EMF_Coil_Form_20mm.3mf
20.0 x 20.0 x 3.79 mm

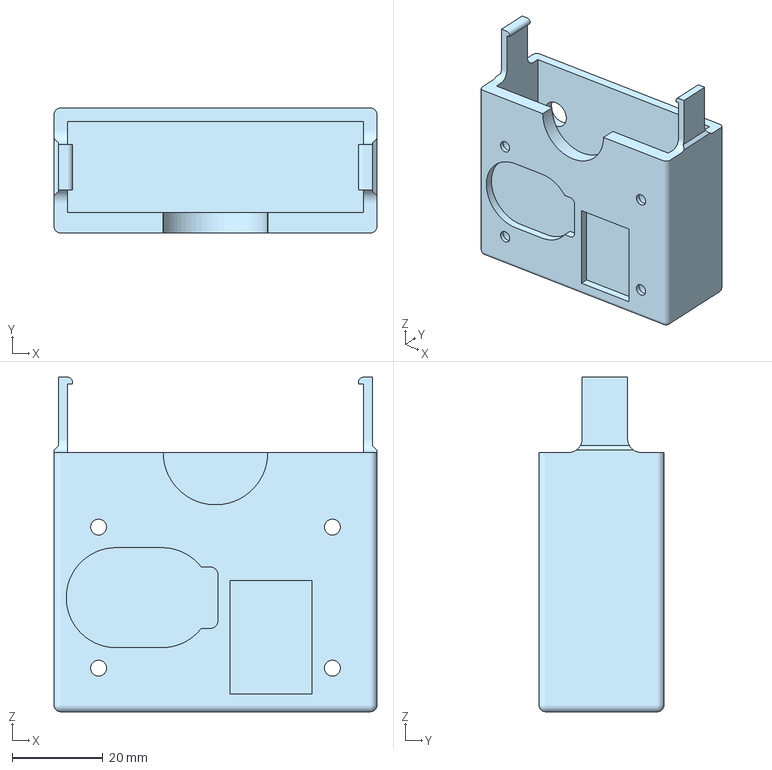
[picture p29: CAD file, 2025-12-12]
EMF_Meter_Replica/3D/AA_Bat_Holder_EMF_r2.3mf
71.0 x 27.5 x 73.6 mm

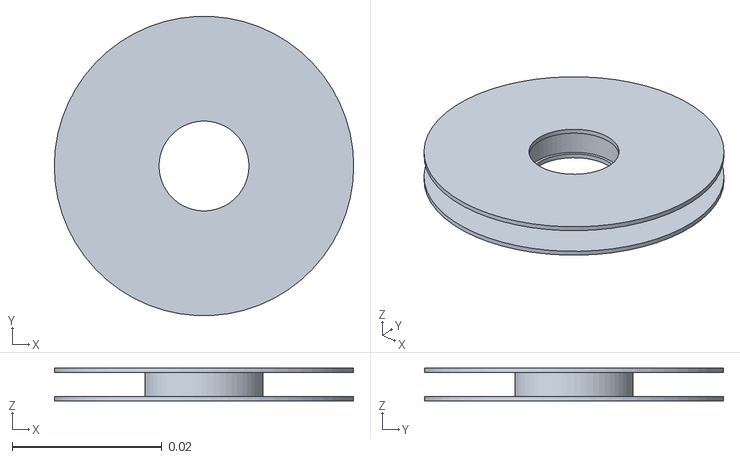
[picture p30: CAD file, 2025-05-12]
EMF_Meter_Replica/3D/EMF_Coil_Form_1.5_inch.stl
0.04 x 0.0399 x 0.00438

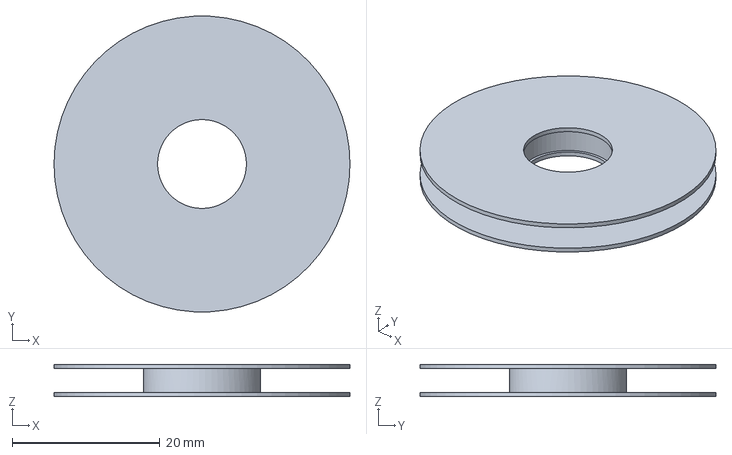
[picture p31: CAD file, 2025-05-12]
EMF_Meter_Replica/3D/EMF_Coil_Form_1_5_inch.3mf
40.0 x 39.9 x 4.38 mm

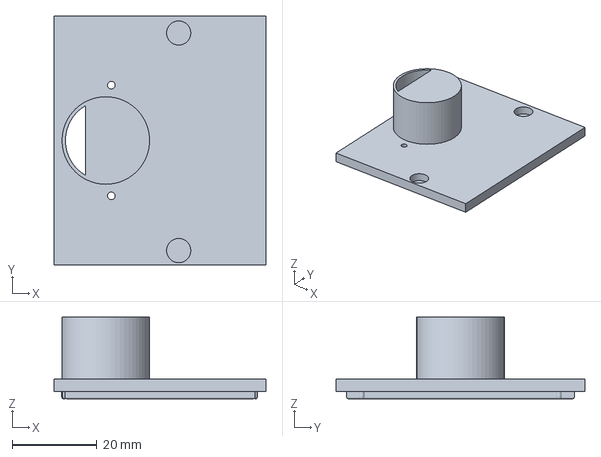
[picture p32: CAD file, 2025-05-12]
EMF_Meter_Replica/3D/EMF_Meter_Base_r1.3mf
49.8 x 58.6 x 19.2 mm

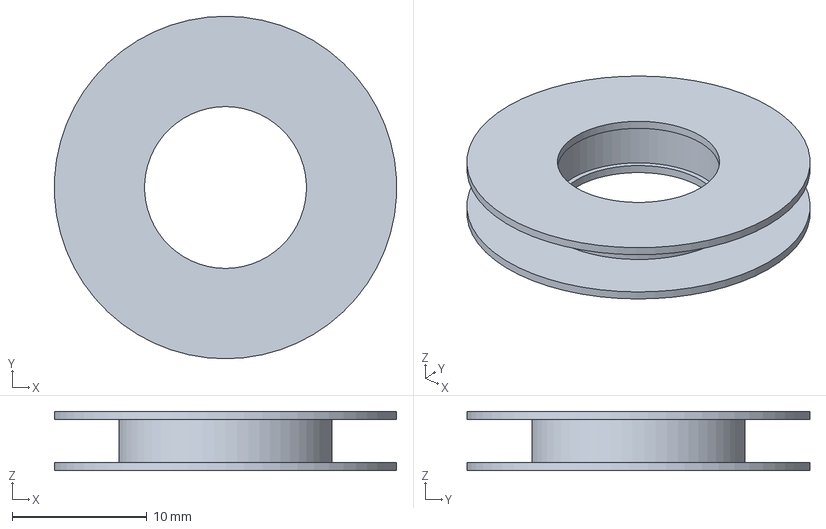
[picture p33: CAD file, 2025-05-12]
EMF_Meter_Replica/3D/EMF_Coil_Form_1_inch.3mf
25.4 x 25.4 x 4.38 mm

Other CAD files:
EMF_Meter_Replica/3D/AA_Battery_Pack_Holder_EMF.3mf
10_LED_EMF_Meter_Replica/r1/3D/EMF_P_Clip_5mm_dia.stl
10_LED_EMF_Meter_Replica/r1/3D/EMF_P_Clip_6mm_dia.stl
EMF_Meter_Replica/3D/EMF_Coil_Form_1_inch.stl
EMF_Meter_Replica/3D/EMF_Meter_Base_r1.stl

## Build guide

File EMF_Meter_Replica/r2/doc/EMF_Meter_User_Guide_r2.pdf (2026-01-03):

# EMF Meter User Guide (r2)

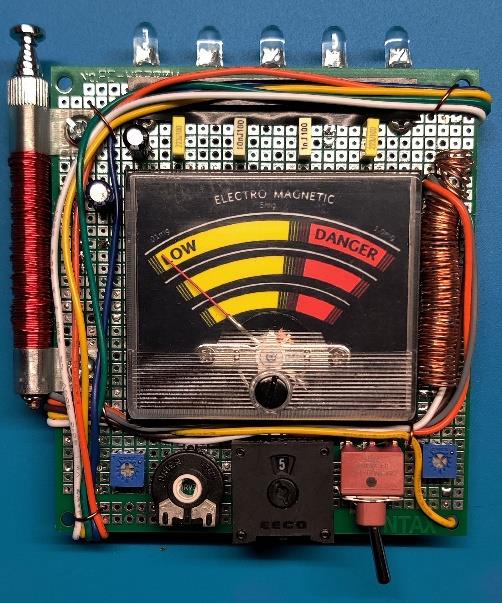
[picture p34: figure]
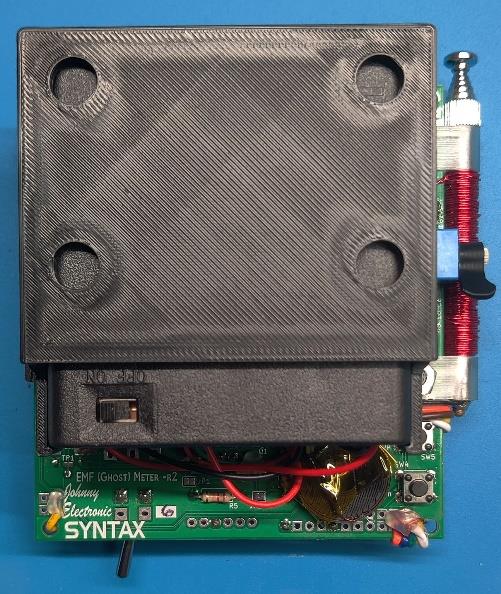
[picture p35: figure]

This EMF Meter was made to be a replica of the one used in the Supernatural TV series. I based my initial version on Sam’s EMF Meter from S4 E13 (and seen in a few other seasons).

This is a functional EMF meter that can detect both Electric and Magnetic fields. The meter was designed to be able to replicate a variety of the meter configurations used in the TV series. It’s a great prop or cosplay item.

## Meter Details (Pre-Assembled Boards)

Due to the availability of certain parts, the pre-assembled meters may vary. The listing for any pre-assembled meter will show the specific items used for that build.

- Dimensions: 86 x 95 mm
- Powered by a 6v AA power pack, 4 AA batteries
- Configured for 4 or 5 top capacitors. (If you ordered a 4-cap version the 5th will be included separately)
- An effort will be made to have the correct capacitor value of 22n for yellow and 10n for white.
- 5 LED BAR display mode
- ATTiny85 to control the MP3 sound effects
- Re-programming possible using an ICSP port.
- SD card with sound files (sound files can be changed if needed)
- Detects E-Field and H-Field signals (Electric and Magnetic Fields) with 3 gain settings for each (-10, 0, +10). No guaranteed accuracy of the meter.
- Functional EECO rotary switch for E-Field gain (will vary based on availability)
- Rotary 4-position switch for H-Field gain
- 3326/3362 Series blue potentiometers (Smaller version)
- PT15 black potentiometer
- Antenna will vary based on availability. If the ATT 5100 6mm is available it will be used.

## Meter Operation

If you purchased an assembled unit then all adjustments have already been made and a programmed SD card has been installed. Otherwise review the EMF Meter Adjustments and Power Up section in the build guide.

- Install the batteries in the battery pack if you have not already done so.
- To remove the battery pack just pull it straight out from the holder (AA) or use your finger to push the battery out of the holder (9v).
- To insert slide the battery pack in so the power switch is facing out and the clasps are at the edges of the pack. Slide in until it locks into place (AA). For 9v just slide the cell back in to the holder.
- Check that the SD card is inserted properly.
- For AA batteries check that the power switch is in the ON position.
- Flip the front power switch to the ON position, left.
- You should see the meter deflect briefly and the EMF detected sound played.
- Use the Test button to force an EMF event otherwise you can move around and see if any Electric or Magnetic fields can be detected.
- There is a VOLUME UP and DOWN switch to control the meter sound. It is easiest to adjust the sound volume while pressing the test switch. The sound volume level will be saved every 5 seconds.
- Hold the meter on the right side so you do not block E-field reception. For greater E-field detection extend the telescopic antenna.
- Review the remaining sections for gain adjustments of the meter.
- This meter was designed as a novelty item and no calibration of field strengths was performed.

### Meter Settings

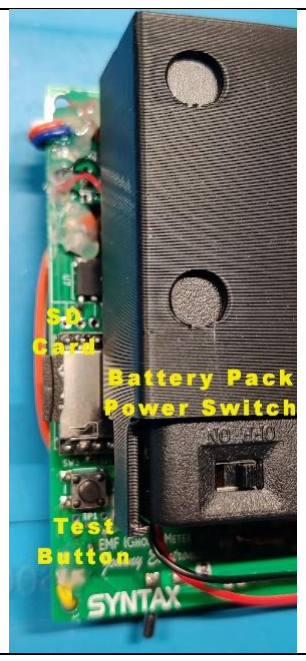
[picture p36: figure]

Left Back Side of Meter

Battery Pack Power – Main power switch

SD Card – Contains sound files for meter operation. If you do not hear any sound check that the SD card is inserted properly. Press in to release and insert. You should hear a click when inserting.

Test Button – This button can be pressed to simulate an EMF event.

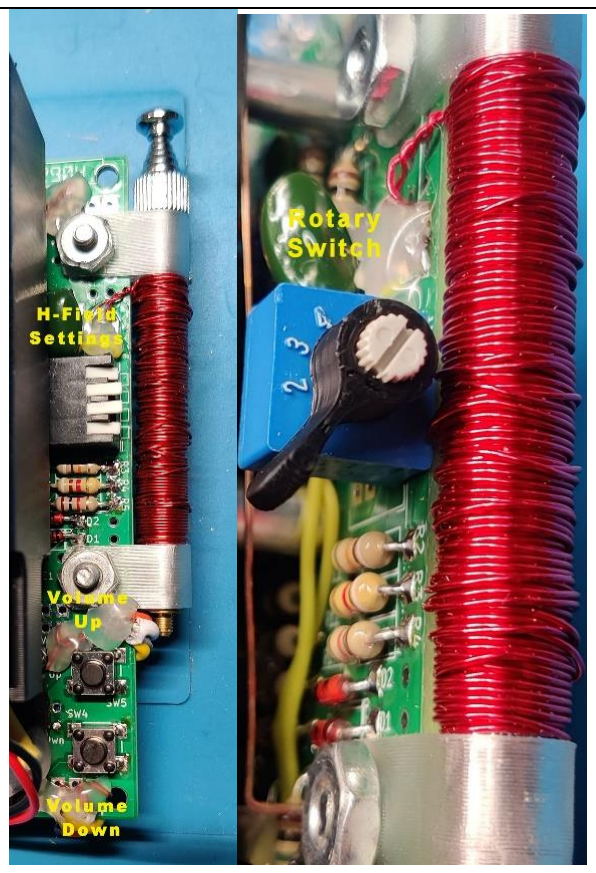
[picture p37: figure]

| Right Back Side of Meter Piano DIP/Rotary Switch (SW2) – Used to control the H-Field gain as well as enable and disable of H-Field detection. Piano Switch: The lever DIP switch is used to control the gain and operation of the H field circuit. The table below shows the setting for each switch position. Rotary Switch: Turn the selection dial to the desired setting.
Piano | Rotary | Gain Setting
1 | 4 | Gain x10: Provides a gain setting of 10
2 | 3 | Gain x1: Provides a gain setting of 1
3 | 2 | Gain x0.1: Provides a gain setting of 0.1
4 | 1 | Disable: Disables the checking for H-fields.
For normal operation with the piano switch there must always be one selection enabled.

Volume Control
Up/Down – Used to control the volume level of the meter sound

### Meter Adjustments

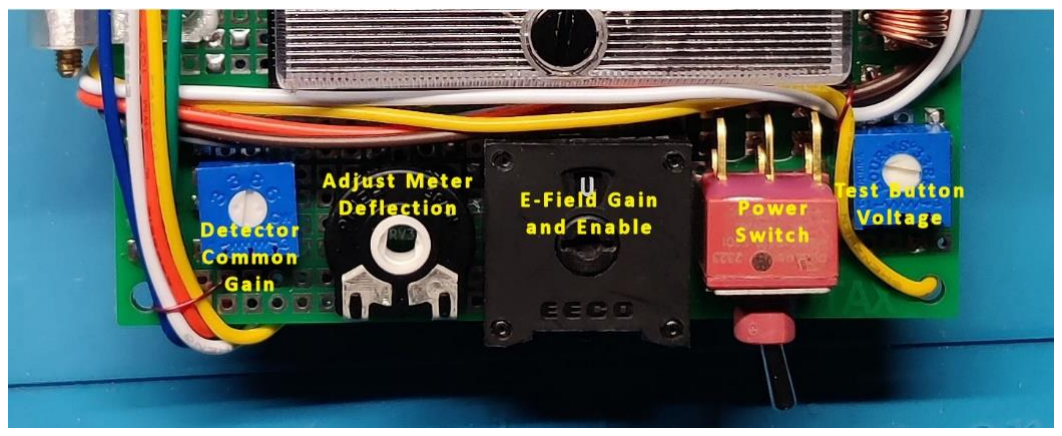
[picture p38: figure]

RV1 | Test button voltage – CCW increases level
RV2 | Detector Common Gain – CW decreases gain. Reduce gain if the H/E-Field is too sensitive or increase for more sensitivity.
RV3 | Meter Deflection – CW increases deflection

EECO Switch (SW1) – E-Field Gain and Enable/Disable

The EECO switch installed in this meter is a 271131M and the table below will show the various E-Field gain settings based on the switch position.
Dial | Function
0-7 | Disabled
8-11 | Gain +10
12 | Gain 0
13 | Gain -10
14 | Gain 0

15 | Gain -10

### SD Card (Sound Files, MP3)

The sound files are stored in a folder named /mp3 on the SD card. Six files are available but only five are used in the program for the EMF meter. This table lists the files, functionality, and associated code define. The sound files are available in Github. The link is in the references section at the end of this document.

If you wish to change the files, they must be in the mp3 folder and start with the same 4-digit number. Ie: 0001_emf start.mp3 could change to 0001 my custom sound.mp3
Keeping the file duration to the same length is suggested but not required.
File Name | Function/Duration
0001_emf start.mp3 | Initial startup when a signal is detected or test button pressed, 0.238s
0002_emf low short2.mp3 | Used for mid-point signals that are neither high or low, 0.400s
0003_emf steady short.mp3 | Short high tone - Not used
0004_emf steady long.mp3 | Long high tone when signal reaches maximum, 1.435s
0005_emf steady end.mp3 | Signal going back down to off, 0.282s
0006_emf power up.mp3 | Used for initial setup/power on (5 LED)
0007_emf power up.mp3 | Used for initial setup/power on (10 LED)

### Reprogramming the ATTiny85

ICSP Header

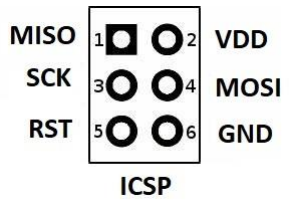
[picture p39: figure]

An In Circuit Serial Programming (ICSP) port is provided for reprograming the ATTiny part. The ICSP connector follows this layout which is the same used for Arduino boards. There are a number of YouTube videos showing various methods for programming including using UNO or Nano boards as an AVR In System Programmer using the ArduinoISP sketch.

I also offer a soft touch programming cable to eliminate the ICSP header and connect directly to the board.

## References

- Github: Development board documentation, schematics, and related files.
- https://github.com/JohnnyElectronic/EMF_Meters/
- YouTube: Board assembly and project videos that are related to this project.
- https://www.youtube.com/@Johnny_Electronic

Disclaimer

This information is provided “as-is” with no representation or warranty of any kind whether express or implied. However, I’ve tried to make this document (as well as the supporting videos) as useful and accurate as possible. If you find something that is incorrect or confusing, please let me know as I would like to make the correction so others will not have the same issue.

This meter is for entertainment purposes only and there is no representation as to the accuracy of the meter readings.

Feel free to email me any time for issues you may have with this build.
johnnyelectronic1@gmail.com

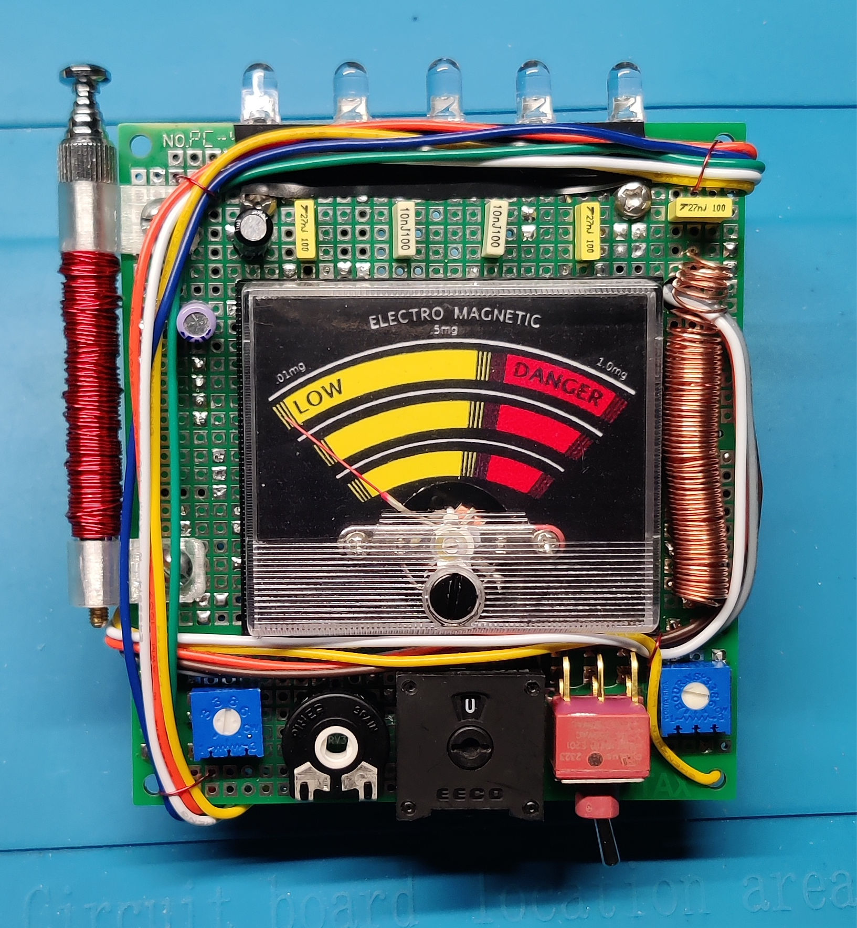
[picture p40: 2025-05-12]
EMF_Meter_Replica/r1/img/EMF_Meter_9v_Assembled_f.jpg

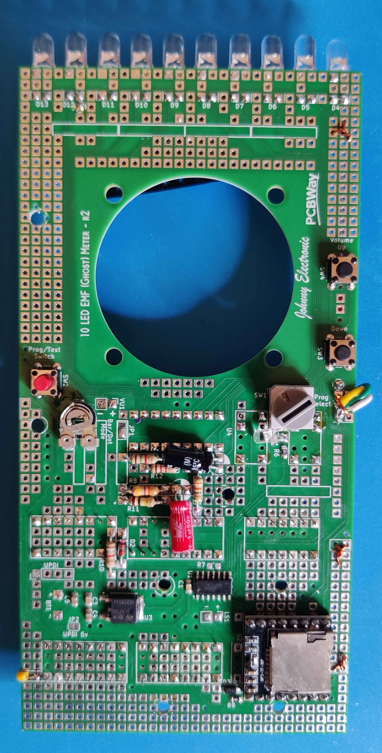
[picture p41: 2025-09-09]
10_LED_EMF_Meter_Replica/r2/img/10_LED_EMF_partial_assembly_back.jpg

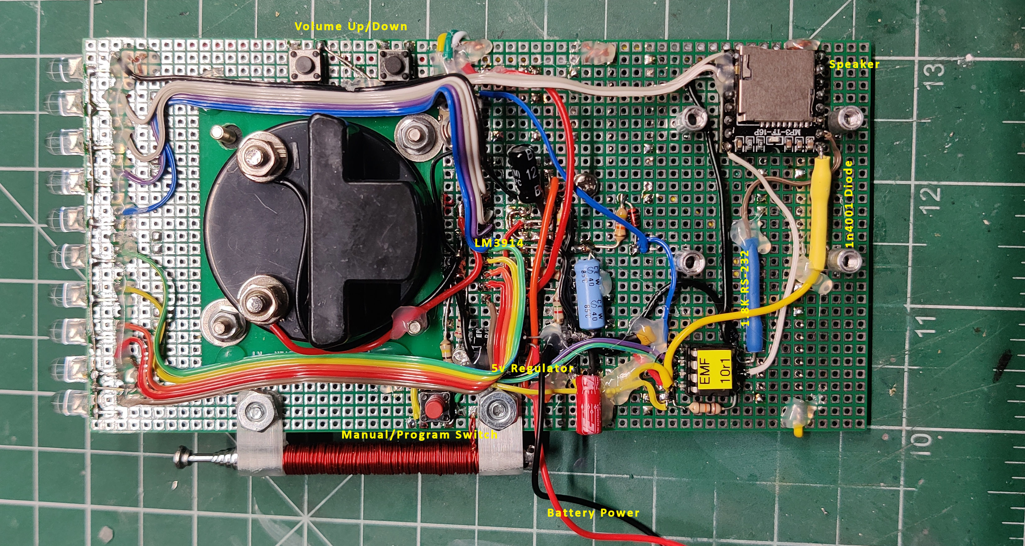
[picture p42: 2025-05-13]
10_LED_EMF_Meter_Replica/r1/img/partial assembly comments.jpg

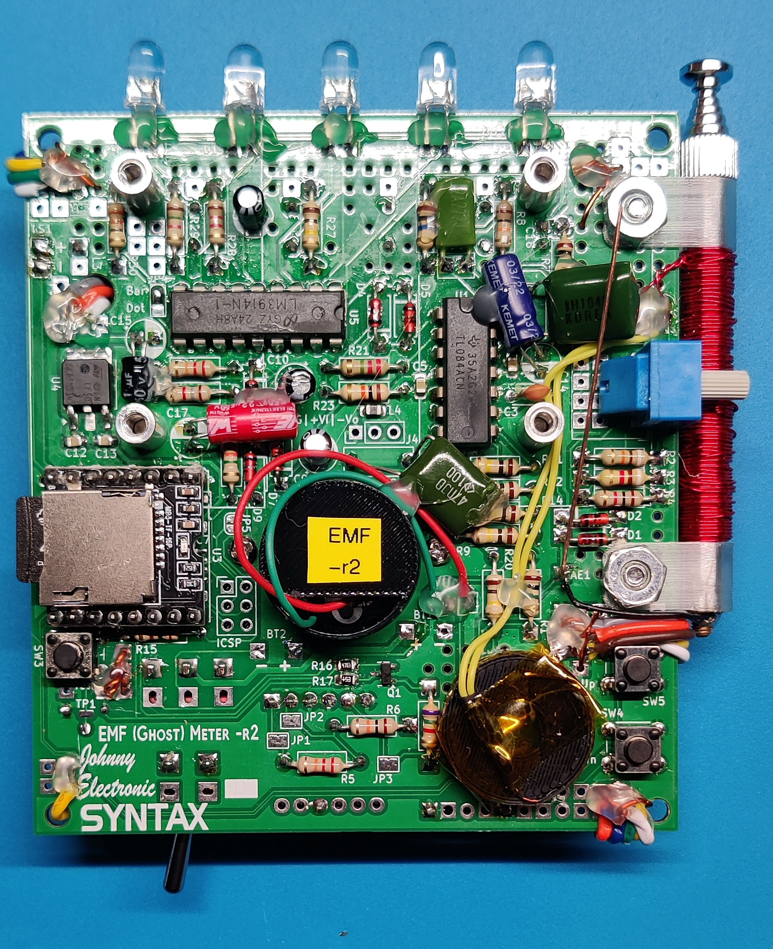
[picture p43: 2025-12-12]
EMF_Meter_Replica/r2/img/PCB_partial assembly_b.jpg

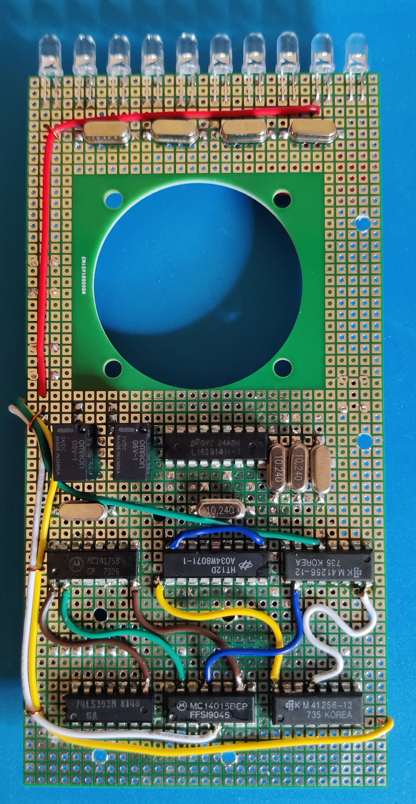
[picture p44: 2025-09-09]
10_LED_EMF_Meter_Replica/r2/img/10_LED_EMF_partial_assembly_front.jpg

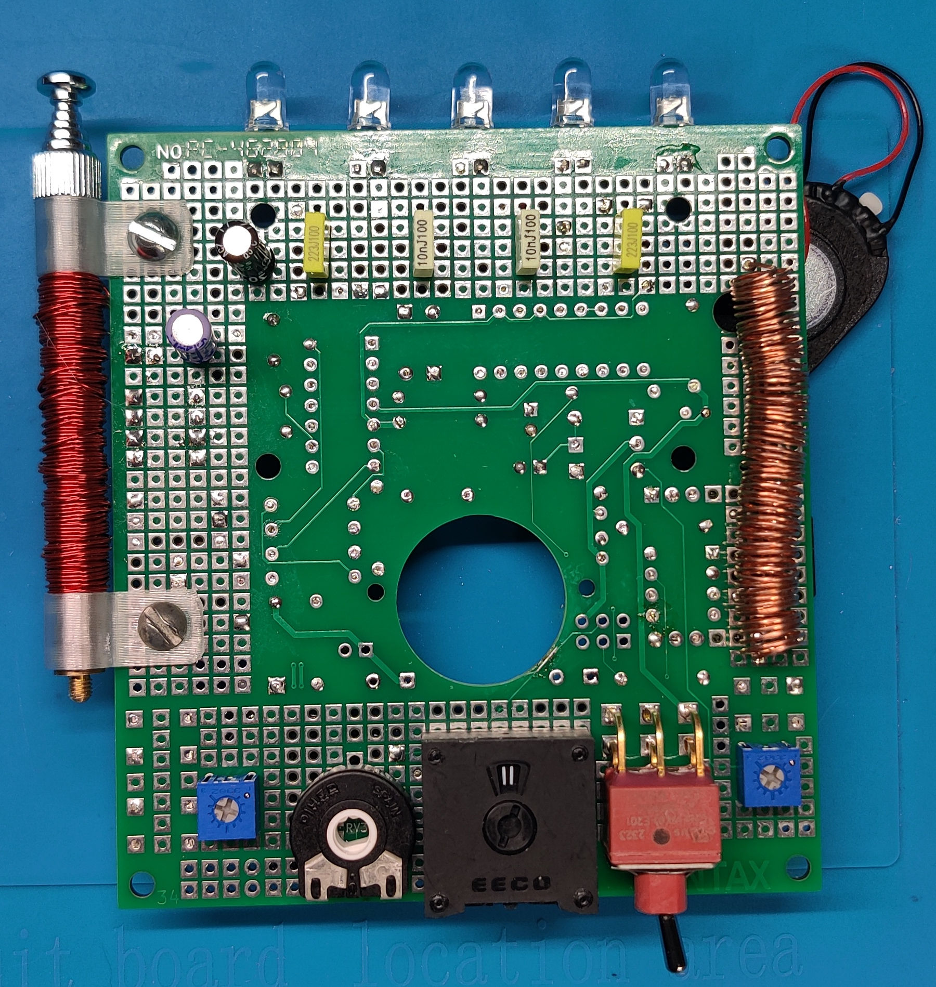
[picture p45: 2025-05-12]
EMF_Meter_Replica/r1/img/Partial_Assembly1.jpg

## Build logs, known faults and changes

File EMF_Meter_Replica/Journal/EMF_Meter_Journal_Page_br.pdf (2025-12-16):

o

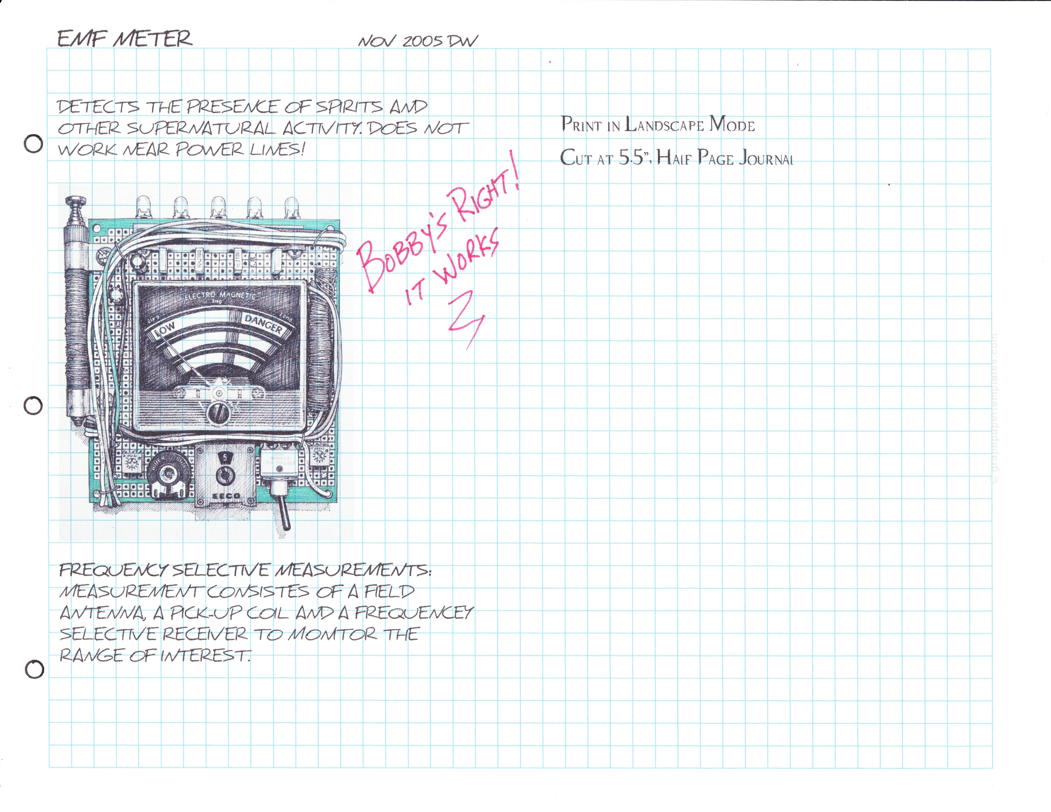
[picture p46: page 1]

€lt/ff | No\/ zoos
W | -rT{€ ru{S*\,tr tr Sn&ms A,W
crrci{rz sttff&NATURAL ACIT\/ W. Ws n/sr | PnrNr ri.r LnNDSCApE MoDE

Cur AT 5.5", Hnrr Pncc JouRNAr

r_REau5,\KY1€L€CTTV€ suWt4*\rr5
Nl€ AsU {Z{/ti€ lvT Co n&f s -rfs ffi A fi{ L^12
A^ITENNA, A frU*,J? {A L A^fr} A W€qt{/\/{tr STL{CTTV{SEGIVfiZTp TTE
%ANG{ tr Inlrfj?€p7 O

I
r-

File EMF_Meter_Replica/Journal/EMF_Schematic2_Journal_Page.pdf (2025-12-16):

## En/tf

## O-rn(rl

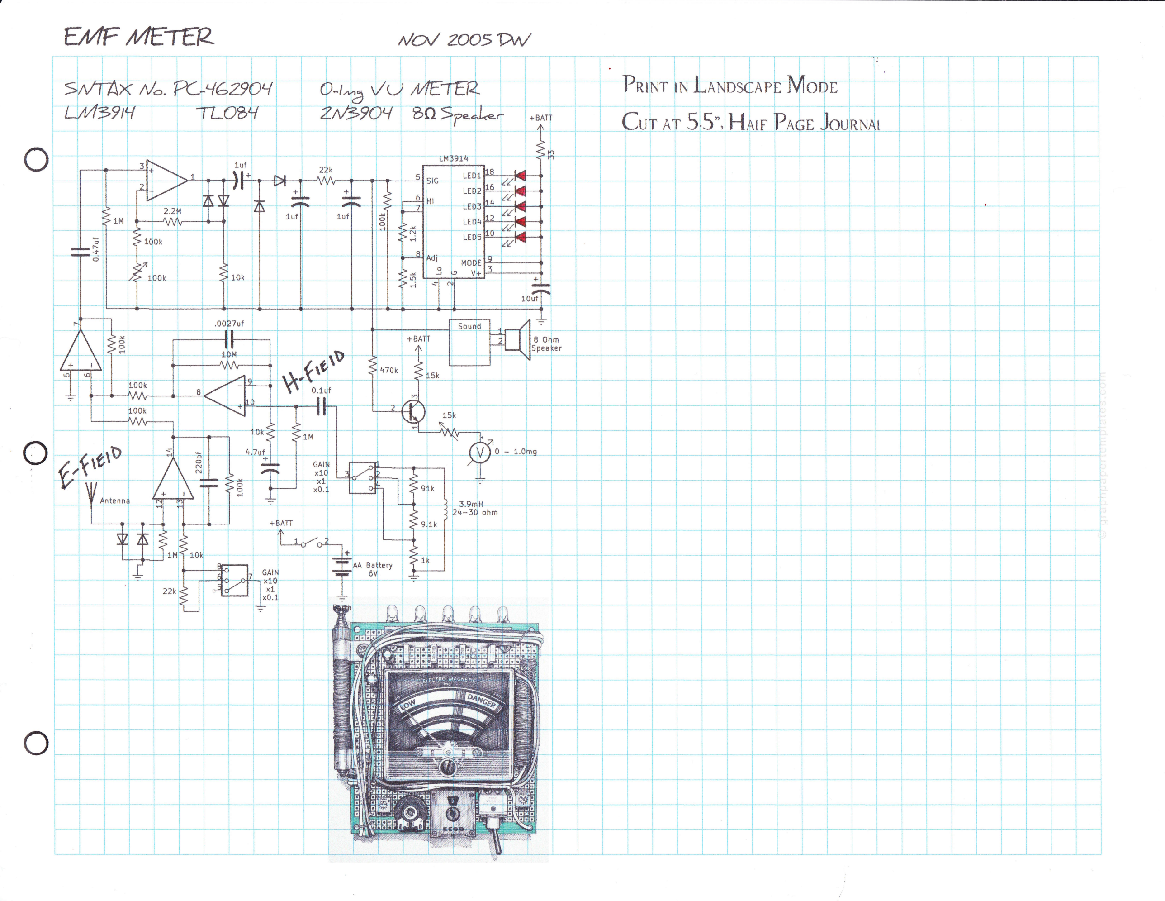
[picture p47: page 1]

5ffix No.?C^qaz?c.{ tal=?r{ TLCU.{

Mo\/ zoos

Z/\B9O'{ AO S7*,.L-. i

Pnl:Nr ru LANDSCAPE MonE
Cur Ar 5.5", Harr Pnce JouRNAr

o

LEDl

LED2
LED]

LED4

LED5

+l+

luf I | tuf

Al**z"z-,
-E

r--l

r- -+

ohm

't\-

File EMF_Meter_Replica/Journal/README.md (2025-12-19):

# EMF Meter Replica - Winchester Journal Pages

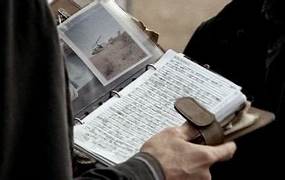
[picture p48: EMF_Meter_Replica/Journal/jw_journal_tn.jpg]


Here is a collection of journal pages for the EMF meter replica. The pages are available in PDF or PNG format and include various options.
Here are some thumbnail images with the file descriptions to help you choose what works for your journal.

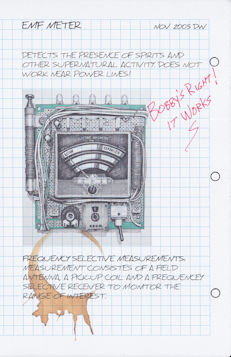
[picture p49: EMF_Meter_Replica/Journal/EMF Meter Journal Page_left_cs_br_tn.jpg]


**A sketch representation of the EMF meter. These files are configured for the left side of the journal so that it can be paired with one of the schematic pages on the right side.**

-EMF Meter Journal Page_left        - plain version

-EMF Meter Journal Page_left_br     - with Bobby's comment

-EMF Meter Journal Page_left_cs     - with coffee stain

-EMF Meter Journal Page_left_cs_br  - everything, coffee stain and Bobby's comment



**A sketch representation of the EMF meter. These files are configured for the right side of the journal.**

-EMF_Meter_Journal_Page             - plain version

-EMF_Meter_Journal_Page_br          - with Bobby's comment   

-EMF_Meter_Journal_Page_cs          - with coffee stain     

-EMF_Meter_Journal_Page_cs_br       - everything, coffee stain and Bobby's comment 

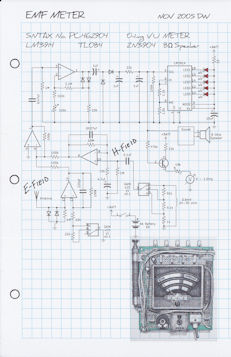
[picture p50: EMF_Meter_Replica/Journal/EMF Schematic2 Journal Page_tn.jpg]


**A schematic representation of the EFM meter configured for the right side of the journal.**

EMF_Schematic_Journal_Page        - plain version 

EMF_Schematic2_Journal_Page       - with small meter sketch at bottom

**Blank 1/4" blue grid template to print something on the back side of the journal pages.**

blue_1_4inch_grid

## Licensing

This work is licensed under Creative Commons Attribution-ShareAlike 4.0 International. 
To view a copy of this license, visit [https://creativecommons.org/licenses/by-sa/4.0/](https://creativecommons.org/licenses/by-sa/4.0/)

Distributed as-is; no warranty is given.

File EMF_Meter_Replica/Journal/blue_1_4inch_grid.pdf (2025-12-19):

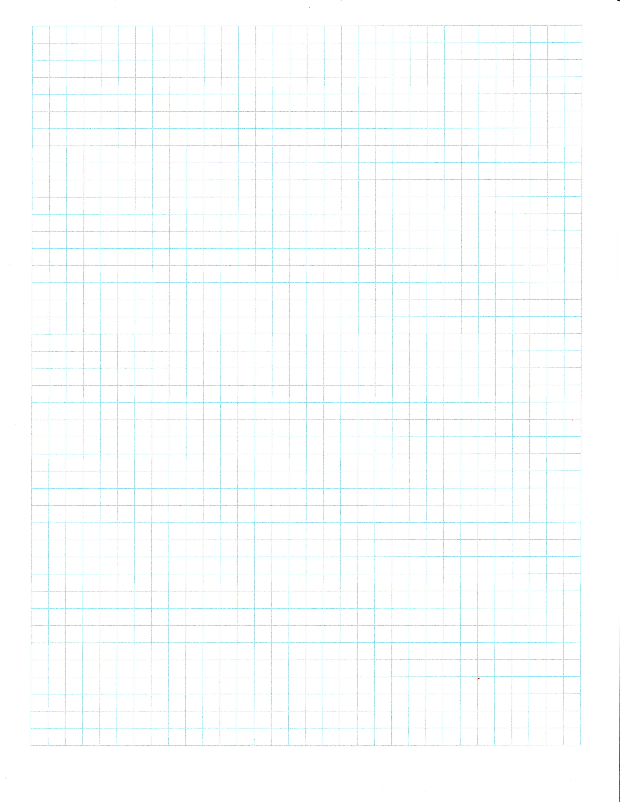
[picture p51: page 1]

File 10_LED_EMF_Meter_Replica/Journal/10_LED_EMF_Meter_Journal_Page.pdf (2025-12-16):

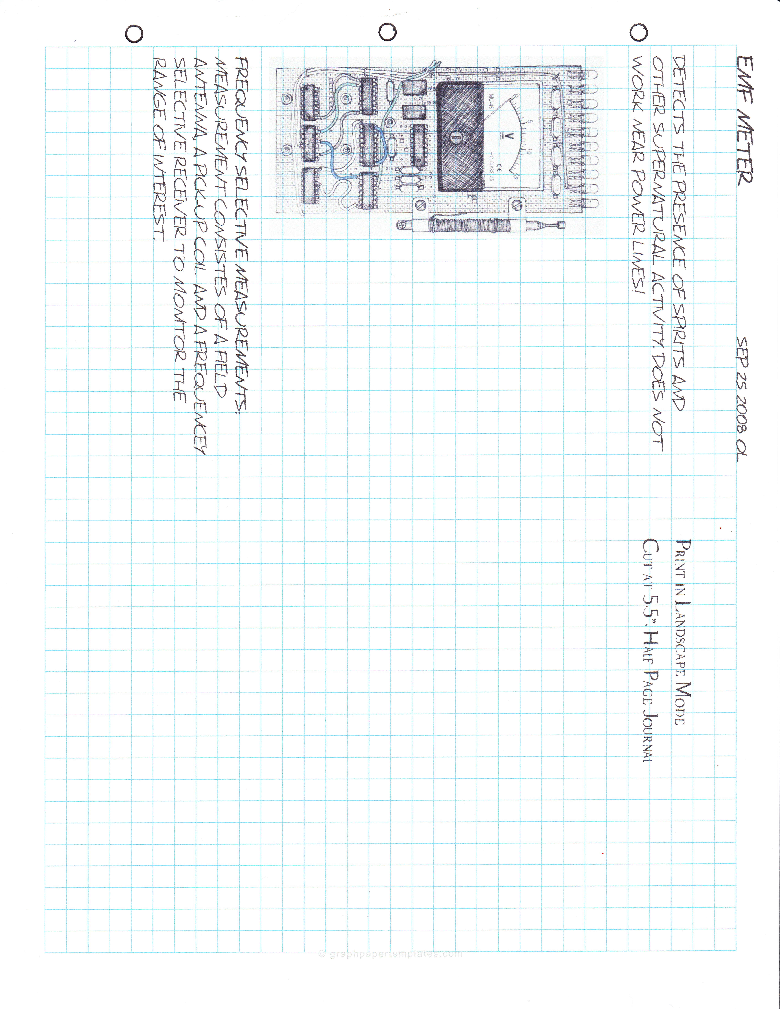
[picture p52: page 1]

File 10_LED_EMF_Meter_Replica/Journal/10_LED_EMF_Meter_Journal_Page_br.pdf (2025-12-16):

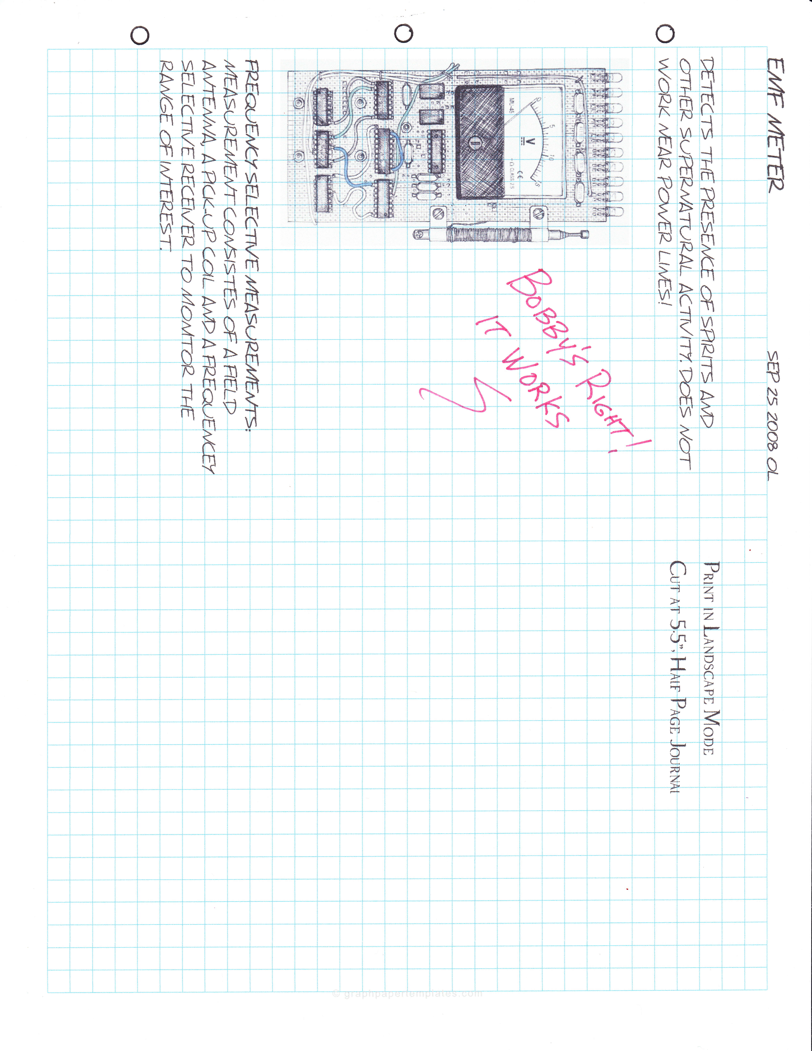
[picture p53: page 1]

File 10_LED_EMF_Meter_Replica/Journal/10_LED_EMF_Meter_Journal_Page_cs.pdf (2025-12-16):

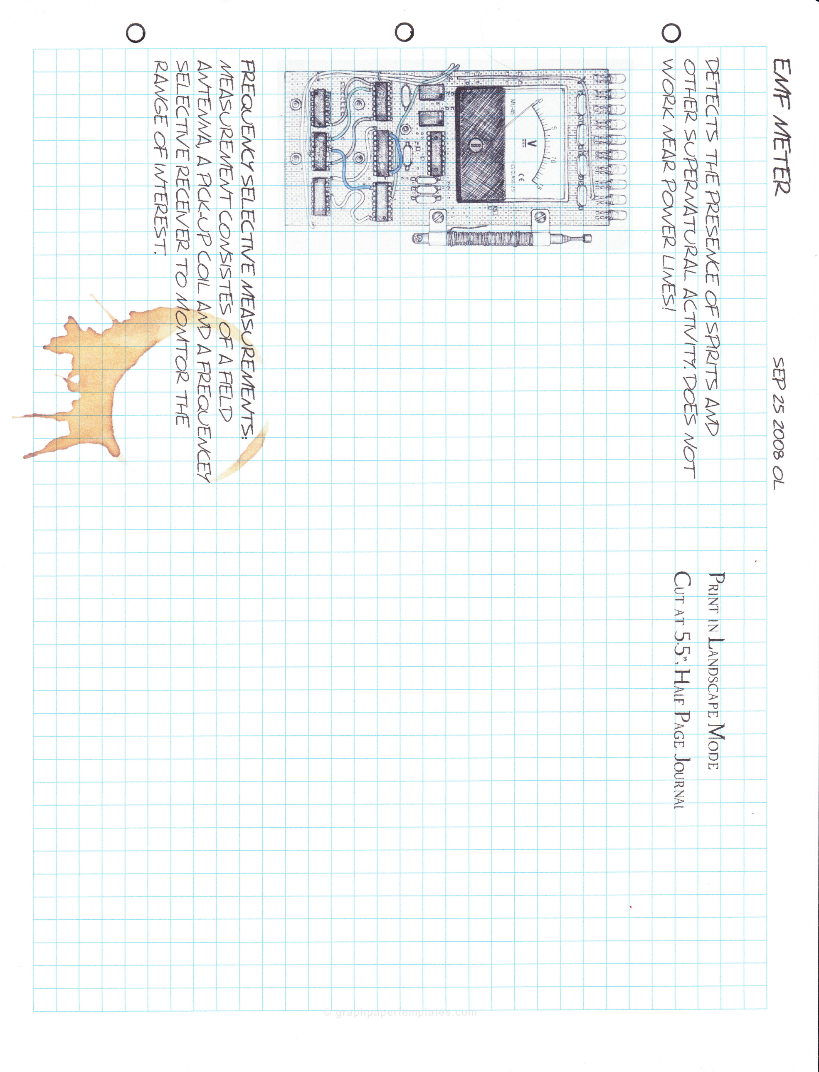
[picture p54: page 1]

$

\
H

VI
s

f\$\fi
f\
o
o
0
p

-t-i

t,titt

li
nittttl

il

I

llttti

ttit -r-1 Hlttt #lrli

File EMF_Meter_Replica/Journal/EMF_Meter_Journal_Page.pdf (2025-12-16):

o

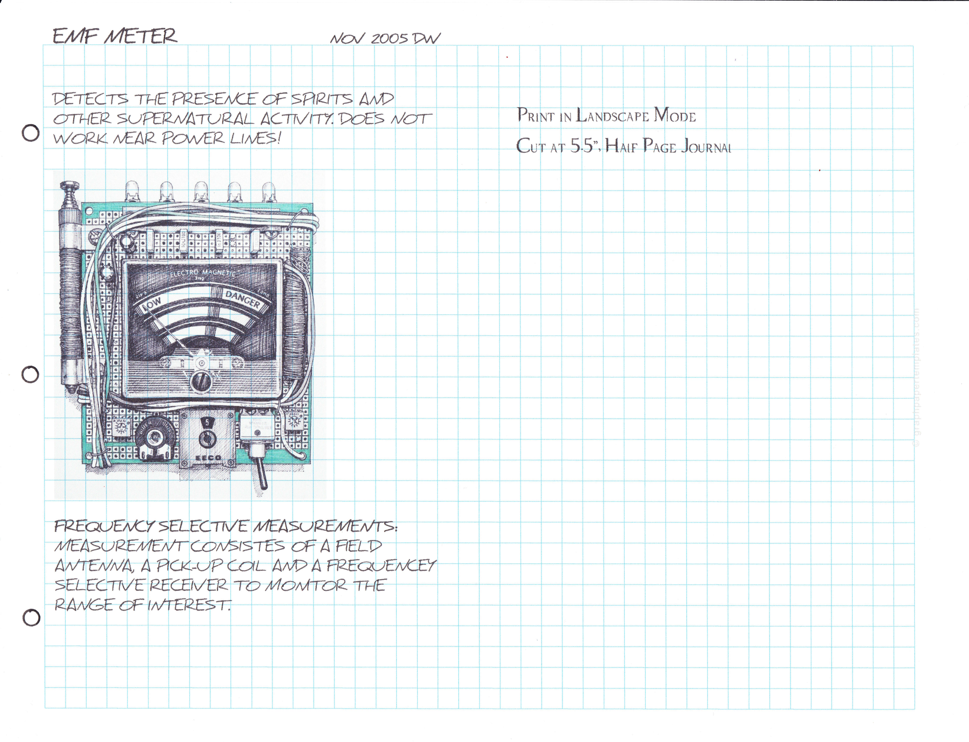
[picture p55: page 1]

glt/ff | /Vo\/ zooSDN
re | TTt€ W{s*\,tr ffi sfr{Zms A,W c*t*Z srtW&n/ArtRAL ACTTV W. Vo{S Msr

-!
wt*tY *€L€.'T-M€ nitAsu eEAIE^,r{s, Su PEI/E ntr Co n${S-TTS ffi A n{U)
A^4EN:VA, A ?t(J<-u? {a L AtW A f?-tqtt/\/ffi srL{cTTv{wfit\/{eTo *t€ P*ANG{trtffi-T*.

PnrNr tr'r I nNDScATE MoDE

Cur AT 5.5', Hnrr Pncr JouRNAr

o

O

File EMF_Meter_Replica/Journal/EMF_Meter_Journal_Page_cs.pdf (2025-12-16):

o

## re TT{€ ruES{/\,G tr sfrRtTs Al\fr2

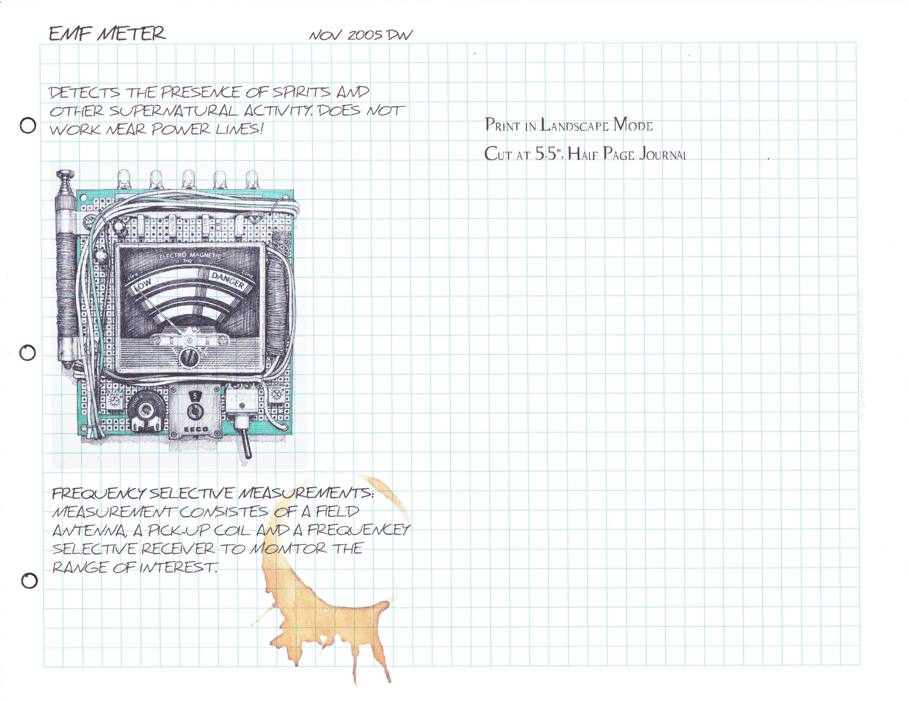
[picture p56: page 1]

€/Ytf | /Vo\/ zoo>TfuV
117gtW /\/€AtZ | LtA/€>l

i
m&cru€/vtY a€L€C-IW€ /vl€Asu*En4€n,ffi, ;
/i4€ A>tt PEuE ttr Co nBr sTfs ff A Ft{tt>

## A^/TEN/V& A 7(r-,o?caL AlW AFL€qt€/\Kfr

s{L€CrrV { WGrl E& To ti o Mro& TT{{

Pnrxr rn LANDSCAPE MonE

Cur AT 5.5", Herr Pncn JouRNAt

O

## O sANG€trtffi%{sr

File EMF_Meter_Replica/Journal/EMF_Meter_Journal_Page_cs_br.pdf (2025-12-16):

o

{nltf | Mol zooshM

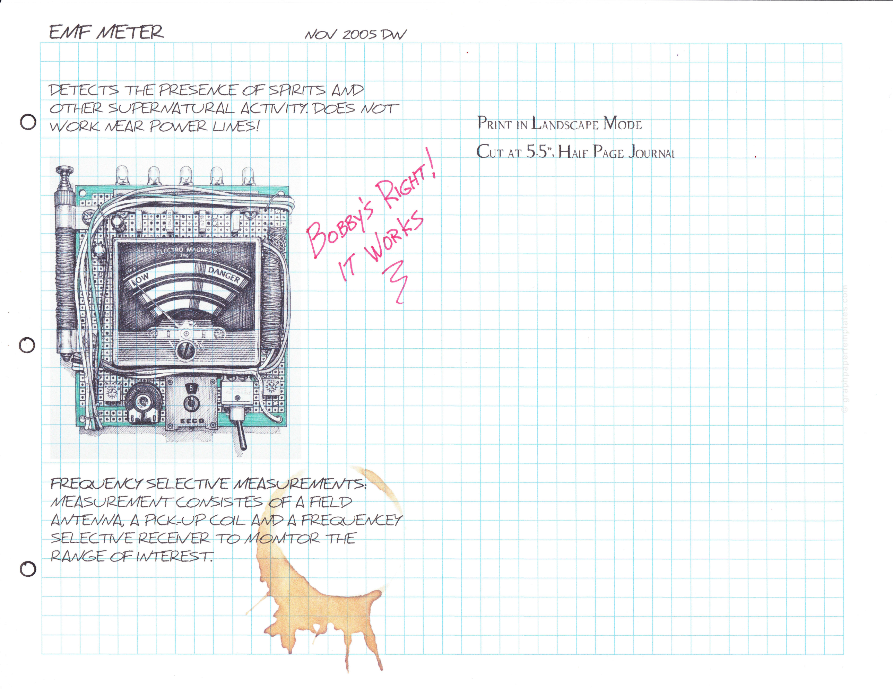
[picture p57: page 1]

re | r+r€ rcEs{^/tr ffi sfrr*Ts AlW
11t7gt{M A/€AP' | LtA/€rl

## FBgaU€/\Ly 5.EL€C-1T\/€ /ti€ASUWn/f€ltTT, i

## /4€ A>u Wrtrl{tff Co n,5lt' Stfs ff A Ft€tr?

# A/\/[E/\//VA, A frCKu?(oL A,W AfPl€cut{l\Kfr

## S{L€C|T\/ { q-EGI\/ {g TO M O MTCE TH{

# O eA$G{ffrffirzfsr

Pnrnr rr.r LnNDSCAPE MonE
Cur nr 5.5', Hnrr Pnce JounNAr ; l l illd\ i i l,,qo1

r

# r :Zf-17 *i iT,( u ffi.ioYZ P;ul i..\DFi' i L.i(ile-r ii)|:r11 r

$ I

T

## I- ttlt+*-+ ttlt

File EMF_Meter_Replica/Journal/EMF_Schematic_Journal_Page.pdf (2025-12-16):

{n/tf | /\/o\/ zooSDM | ''

## ?Cqa29c.{ -TLCbr{

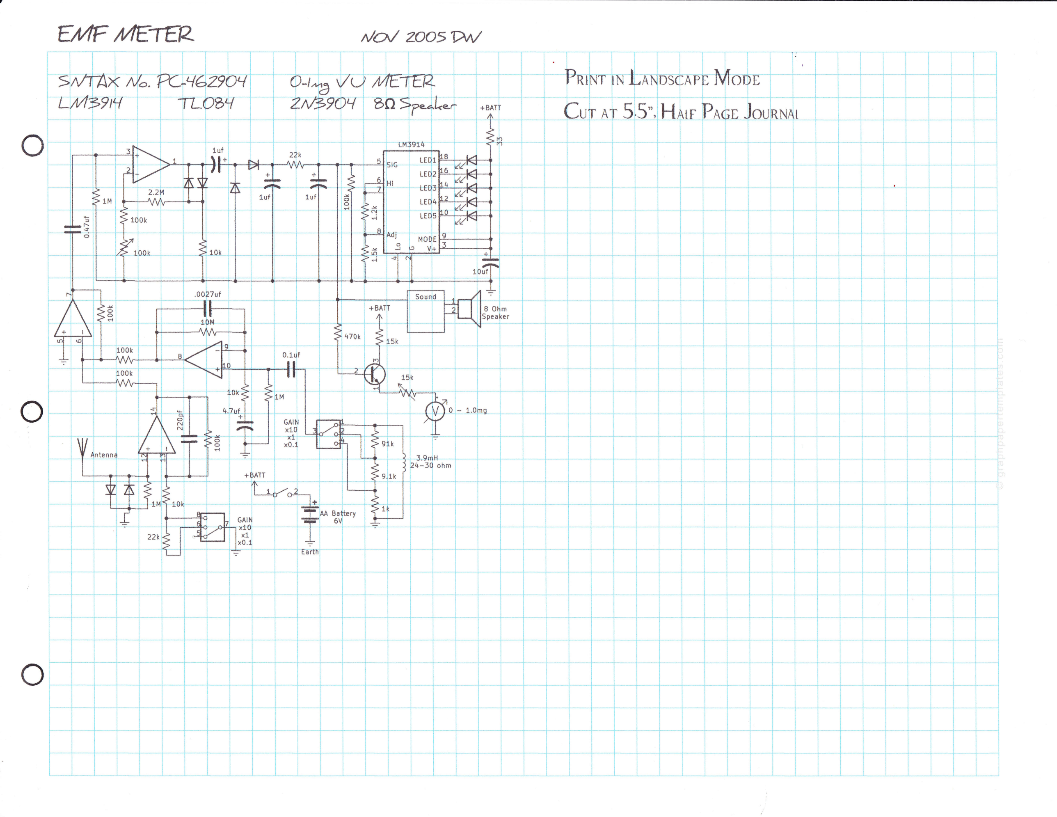
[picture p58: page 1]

,
DSCAPI MOD[..

Herr Pncc JouRNAr

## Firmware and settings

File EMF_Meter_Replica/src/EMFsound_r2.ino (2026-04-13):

/******************************************************************************************
Supernatural EMF Meter Replica

EMF ATTiny85 Code
Release: 2.0 (Label: EMF / r2)

Compatible with PCB version r-1 (based on modifications) using EMF_V1_2 define
- 1.1 reduces the gap between high tone track play
- 1.2 requires jumper between ATTiny85 pin 6 to DFPlayer pin 3

Compatible with PCB version r-2 using EMF_V2_0 define
- 2.0 New ATTiny85 pin mapping for r2 PCB
- Updated audio file and added DFP reset code for DFP play lockup
- Added BUSY PIN detect around EMF_TONE_LOW section
- DFP Lockup only seems to be with the JL AC, AF... series so far. Could not create the issue with JL AB...,
  TD5580 and DFROBOT versions. Noticed that DFRobot has a post play amp click. Need to rview further before
  using in EMF design.

Johnny Electronic
https://github.com/JohnnyElectronic
https://www.youtube.com/@Johnny_Electronic

Description **********************************************
This code uses an ATTiny 85 to monitor EMF levels from the core logic and control a 
DF Player audio device (MP3Player). The EMF level (or test button) will determine the sound file 
to be played and the voltage applied to a LED Display and VU meter element.

Copyright **********************************************
Copyright 2024 by John Bennett, aka Johnny Electronic.

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
  This program is distributed in the hope that it will be useful, but WITHOUT ANY WARRANTY; 
  without even the implied warranty of MERCHANTABILITY or FITNESS FOR A PARTICULAR PURPOSE. 
  See the GNU General Public License for more details.

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
DFPlayer **********************************************
DFPlayer - A Mini MP3 Player For Arduino
 <https://www.dfrobot.com/product-1121.html>

 1.Connection and Diagrams can be found here
 <https://www.dfrobot.com/wiki/index.php/DFPlayer_Mini_SKU:DFR0299#Connection_Diagram>

 2. The DF files used in this version are a custom creation.
*******************************************************************************************/

#include "DFPlayer.h"
#include <EEPROM.h>

//#define DFP_DEBUG     /* Enables display of received data for query requests to Serial, Nano only */
//#define EMF_DEBUG     /* Enables display of EMF data for debug, Nano only */

//#define NANO
#define ATTINY

// Comment out both EMF_V1_2 and EMF_V2_0 for early version <= 1.1
//#define EMF_V1_2        /* Enable version 1.2 code, stores changed volume level every 3s, reloads between power cycles, requires PCB r1 */
#define EMF_V2_0        /* Enable version 2.0 code, all features of 1.2 w/ new ATTiny 85 SOIC-8 pin mapping, requires PCB r2 */

// Not all pins on the Mega and Mega 2560 boards support change interrupts, 
// so only the following can be used for RX: 10, 11, 12, 13, 14, 15, 50, 51, 52, 53, A8 (62), A9 (63), A10 (64), A11 (65), A12 (66), A13 (67), A14 (68), A15 (69). 

// Nano Pinouts
//DFPlayer.h settings
#ifdef NANO
#define  DFP_RX_PIN   12     // Pin Assigned for serial RX, set to -1 if not used - D12 Uno/Nano
#define  DFP_TX_PIN    8     // Pin Assigned for serial TX  - D8 Uno/Nano
#define  DFP_BUSY_PIN  2     // Pin Assigned for busy detection, set to -1 if not used
#define  SENSOR_PIN   A1     // EMF input level
#define  METER_PIN    11     // PWM output to drive VU meter
#define  DFP_LOCKUP    3     // Flags DFP lockup condition, used for LED
#endif

// ATtiny85 Pinouts
// ---------------------------------------------------------
// ATTny85: AVR_ATtiny85
//                          _____
// (Reset)  (A0) PB5  5   1|*    |8  VCC
// (Xtal)   (A3) PB3  3   2|     |7  2   PB2 (A1)(SCK)
// (Xtal)   (A2) PB4  4   3|     |6  1~  PB1     (MISO)
//                   GND  4|_____|5  0~  PB0     (MOSI)
// 
// ---------------------------------------------------------
#ifdef ATTINY

#ifdef EMF_V2_0
    #define DFP_BUSY_PIN 0     // ATTiny85 PB0 (Pin 5), pin Assigned for busy detection, set to -1 if not used
    #define DFP_TX_PIN   3     // ATTiny85 PB3 (Pin 2), pin Assigned for serial TX, Connects to module's RX pin 2
    #define DFP_RX_PIN   4     // ATTiny85 PB4 (Pin 3), pin Assigned for serial RX, Connects to module's TX pin 3, set to -1 if not used
    #define SENSOR_PIN   A1    // ATTiny85 A1  (Pin 7), EMF input level
    #define METER_PIN    1     // ATTiny85 PB1 (Pin 6), PWM output to drive VU/LED meter (Power up pulse and TBD usage)
#else
    #define DFP_BUSY_PIN  3     // ATTiny85 PB3 (Pin 2), pin Assigned for busy detection, set to -1 if not used
    #define DFP_TX_PIN    4     // ATTiny85 PB4 (Pin 3), pin Assigned for serial TX, Connects to module's RX pin 2
    #define DFP_RX_PIN    1     // ATTiny85 PB1 (Pin 6), pin Assigned for serial RX, Connects to module's TX pin 3, set to -1 if not used
    #define SENSOR_PIN   A1     // ATTiny85 A1  (Pin 7), EMF input level
    #define METER_PIN    0      // ATTiny85 PB0 (Pin 5), PWM output to drive VU meter
#endif

#endif

SoftwareSerial dfpSerial (DFP_RX_PIN, DFP_TX_PIN); // RX, TX

/* Audio Tracks (mp3 folder on SD card):
1- 0001_emf start                       0.238s
2- 0002_emf low short2                  0.400s
3- 0003_emf steady short (High Tone)    0.568s
4- 0004_emf steady long (High Tone)     1.435s
5- 0005_emf end                         0.282s
6- 0006_emf power up                    copy of emf start, 0.238s
*/
#define EMF_TONE_START   1
#define EMF_TONE_LOW     2
#define EMF_TONE_STEADY  3
#define EMF_TONE_STEADYL 4
#define EMF_TONE_END     5
#define EMF_POWER_UP     6

// EMF States
#define EMF_DETECT  0   // Idle or monitoring for EMF levels
#define EMF_FOUND   1   // Found an EMF level

/* EMF Levels (1.3v max scale) mapped to input voltage and LED indication
 LED   |  Voltage | Sensor Level
            0         0
  1         0.260     53
            0.300     60
            0.500     103
  2         0.530     110
            0.602     125 
            0.700     146
  3         0.750     157
            1v        210
  4         1.125     235          
  5         1.250     261
            1.30      271
            2v        421
            2.5       525
            3.0       633
*/

/* EMF Levels (3v max scale) mapped to input voltage and LED indication
 LED   |  Voltage | Sensor Level
            0         0
  1         0.60     125
  2         1.2      251
  3         1.8      380
            2.1      440
  4         2.4      504
                  
  5         3.0      632
*/

/* Set values for 1.5v, 3v, or 5v scale range */
#define MAX_METER_LVL   158    /* Set to 80 for 1.5v, 158 for 3v, 255 for 5v scale */
#define MTR_TEST_LEVEL  118    /* Set to 50 for 1.5v, 118 for 3v, 215 for 5v scale */
#define EMF_LEVEL_LOW   250    /* Set to 110 for 1.5v scale or 250 for 3v scale (Approximatley LED 2) */
#define EMF_LEVEL_HIGH  440    /* Set to 200 for 1.5v scale or 440 for 3v scale (Approximatley LED 3 1/2) */

#define EMF_TONE_LOW_DURATION      250     /* Maximum time until replay */   
#define EMF_TONE_STEADYL_DURATION  1200    /* Maximum time until replay */   

#define AUDIO_LEVEL_ADDR     0          // Memory address of EMF audio level setting
#define EMF_AUDIO_LEVEL      20         // Typical 15-20 to start
#define EMF_MAX_AUDIO_LEVEL  30         // Highest Level
#define EMF_MIN_AUDIO_LEVEL  2          // Lowest Audible Level
#define EMF_VOL_SAVE_DELAY   3000       // Check for save every 3s 
byte emfVolumeLev = EMF_AUDIO_LEVEL;    // Current or initial DFP volume level for EMF

const int sensorPin = SENSOR_PIN; // select the input pin for the VU level
const int meterPin = METER_PIN;   // Output to VU meter
const int emfDelay = 100;         // 100ms for default freq. Wait delay for checking EMF levels for audio only, 50-200 range, 200 decent but slows mid level sound.
const int dfpInitDelay = 1200;    // Delay time needed for DFP player to initialize.
const int meterMin =  20;         // Minimum level for meter to respond, shuts down PWM when below this level.

int emfDetected = 0;              // Current state of EMF sound to signal detection
int sensorValue = 0;              // variable to store the value coming from the sensor
int meterOutputValue = 0;         // variable to store the converted meter value
int lastSensorValue = 0;          // variable to store the last value coming from the sensor
unsigned long emfTimer = 0;       // Delay timer
unsigned long emfMP3Timer = 0;    // Delay timer
bool emfHighZone = false;         // Tracks MP3 timer state
bool emfMidZone = false;          // Tracks MP3 timer state

#if defined(DFP_DEBUG) || defined(EMF_V1_2) || defined(EMF_V2_0)
int queryVal;
#endif

#ifdef NANO
int dfpLockupCnt = 0;     // Counts the number of resets so far
#endif

#if defined(EMF_V1_2) || defined(EMF_V2_0)
unsigned long emfVolumeSaveTimer = 0;   // Volume save delay timer
#endif


void setup()
{
#if defined(DFP_DEBUG) || defined(EMF_DEBUG)
  Serial.begin(115200);
  Serial.println();
  Serial.println(F("DFPlayer Test"));
  Serial.println(F("Initializing DFPlayer ... (May take 3~5 seconds)"));
  Serial.print(F("DFP_BUSY_PIN:"));
  Serial.println(DFP_BUSY_PIN);
#endif

    dfpSerial.begin (9600);
    dfpSerial.listen();

// Initial setup for DFPlayer.
// Sets up DFP_BUSY_PIN if used to use the busy state/pin of the player. 
// Resets the device and provides a delay based on value provided.
    dfpSetup(DFP_BUSY_PIN, dfpInitDelay);

#if defined(EMF_V1_2) || defined(EMF_V2_0)   /* Save off volume levels between power cycles */
    emfVolumeLev = EEPROM.read(AUDIO_LEVEL_ADDR);

    if ((emfVolumeLev < EMF_MIN_AUDIO_LEVEL) || (emfVolumeLev > EMF_MAX_AUDIO_LEVEL)) {
        // Likely first run, set to a reasonable value. If audio too low, reset to default
        emfVolumeLev = EMF_AUDIO_LEVEL;   
    }
#endif

    dfpSetEq(DFP_EQ_CLASSIC);
    dfpSetVolume(emfVolumeLev);

#ifdef DFP_DEBUG
    queryVal = dfpReadQuery(0);
    Serial.print(F("Params Rst:"));
    Serial.println(queryVal, HEX);

    queryVal = dfpGetVolume();
    Serial.print(F("Params Vol:"));
    Serial.println(queryVal);
#endif

#ifdef NANO
    pinMode(DFP_LOCKUP, OUTPUT);  // DFP play lockup LED
    digitalWrite(DFP_LOCKUP, 0);  // turn the LED off
#endif

  // Power up sound and flick meter for start up visual
  dfpPlayTrackMP3(EMF_POWER_UP);

#if defined(EMF_V1_2) || defined(EMF_V2_0)   /* Set save timer for volume levels between power cycles, deflect meter */
//  analogWrite(meterPin, map(emfVolumeLev, 0, 30, 0, MAX_METER_LVL));   /* Show volume level as a defletion of the VU meter */
  analogWrite(meterPin, MTR_TEST_LEVEL);
  emfVolumeSaveTimer = millis();
#else
  analogWrite(meterPin, MTR_TEST_LEVEL);
#endif

  delay (1500); 
  analogWrite(meterPin,0);
  pinMode(meterPin, INPUT);   // Shut down output 
  delay (400);
  emfTimer = millis();
}

void loop()
{

#ifdef EMF_V1_2 
  sensorValue = analogRead(sensorPin);   // 0 - 1023
  // Setup meter output. Scale the analog value, and write to the meter output pin based on the selected scale range (1.3v / 3v / 5v)
  meterOutputValue = sensorValue / 4;
  // meterOutputValue = map(sensorValue, 0, 632, 0, 255);  /* For 5v mapping */
  meterOutputValue = constrain(meterOutputValue, 0, MAX_METER_LVL);

  if (meterOutputValue < meterMin) {
    pinMode(meterPin, INPUT);   // Shut down output
  } else {
    analogWrite(meterPin,meterOutputValue);
  }
#endif

    if (millis() - emfTimer > emfDelay) {

#ifndef EMF_V1_2 
      sensorValue = analogRead(sensorPin);   // 0 - 1023
#endif


#ifdef EMF_DEBUG
  if (sensorValue != lastSensorValue) {
      Serial.print(F("EMF Lvl:"));
      Serial.println(sensorValue);

      Serial.print(F("Last EMF Lvl:"));
      Serial.println(lastSensorValue);

      Serial.print(F("EMF Detect:"));
      Serial.println(emfDetected);
  }
#endif

      /* Checking for valid signal detected, startup */
      if (emfDetected == EMF_DETECT) {
        if (sensorValue > EMF_LEVEL_LOW) {
            emfDetected = EMF_FOUND;
            dfpPlayTrackMP3(EMF_TONE_START);

#ifdef EMF_DEBUG
    Serial.print(F("MP3:"));
    Serial.println(EMF_TONE_START);
#endif
        } /* end if > EMF_LEVEL_LOW */

        emfHighZone = false;
        emfMidZone = false;
      } else if (emfDetected == EMF_FOUND) {
        // Low detection state
        if (sensorValue <= EMF_LEVEL_LOW) {
          // Going back down
          dfpPlayTrackMP3(EMF_TONE_END);

#ifdef EMF_DEBUG
        Serial.print(F("MP3:"));
        Serial.println(EMF_TONE_END);
#endif

          emfDetected = EMF_DETECT;  /* Reset back to detect state */
          emfHighZone = false;
          emfMidZone = false;
        } else if ((sensorValue > EMF_LEVEL_LOW) && (sensorValue < EMF_LEVEL_HIGH)) {
          // Low steady detection state
          if (sensorValue >= lastSensorValue) {
            lastSensorValue = sensorValue;
            delay (10);
            sensorValue = analogRead(sensorPin);
            if (sensorValue >= lastSensorValue) {
              // Still mid range or higher
                if (!emfMidZone) {
                    emfMP3Timer = millis();
                    emfMidZone = true;
                }

                // If not busy, play sound. Otherwise catch on next loop
                if (digitalRead(DFP_BUSY_PIN) || ((millis() - emfMP3Timer) > EMF_TONE_LOW_DURATION))  {

                  dfpPlayTrackMP3(EMF_TONE_LOW);
                  emfMP3Timer = millis();
#ifdef EMF_DEBUG
                  Serial.print(F("EMF Lvl:"));
                  Serial.println(sensorValue);
                  Serial.print(F("Last EMF Lvl:"));
                  Serial.println(lastSensorValue);
                  Serial.print(F("MP3:"));
                  Serial.println(EMF_TONE_LOW);
#endif
              } // end if DFP_BUSY_PIN
            } // end if sensorValue, 2nd
          } // end if sensorValue, 1st
          // Else we should be coming down in levels so let the next cycle catch it.
          emfHighZone = false;
        } else {
          /* High detection state
            Check busy line - if still playing skip or if not play again 
            DFP_BUSY_PIN is active low on busy state */
            if (!emfHighZone) {
                emfMP3Timer = millis();
                emfHighZone = true;
                emfMidZone = false;
            }

            if (digitalRead(DFP_BUSY_PIN) || ((millis() - emfMP3Timer) > EMF_TONE_STEADYL_DURATION))  {
                // Replay just under sound file play length, slightly faster than using busy pin
                dfpPlayTrackMP3(EMF_TONE_STEADYL);
                emfMP3Timer = millis();

#ifdef EMF_DEBUG
        Serial.print(F("MP3:"));
        Serial.println(EMF_TONE_STEADYL);
#endif
            } // end if DFP_BUSY_PIN / Timer Check
        } // end if High Level
      } // end if emfDetected 
      
      emfTimer = millis();
  } // End if timer triggered

#if defined(EMF_V1_2) || defined(EMF_V2_0)
  if ((millis() - emfVolumeSaveTimer) > EMF_VOL_SAVE_DELAY) {

      // Check and save volume when idle
      if (emfDetected == EMF_DETECT) {
          /* Check volume level */           
          dfpSerialPurge ();    // Prep for volume read
          //  delay (100);
          queryVal = dfpGetVolume();

#if defined(DFP_DEBUG) || defined(EMF_DEBUG)
          Serial.print(F("Current Vol:"));
          Serial.println(queryVal);
#endif

          queryVal = dfpGetVolume();
          if ((queryVal != emfVolumeLev) && (queryVal <= EMF_MAX_AUDIO_LEVEL) && (queryVal >= EMF_MIN_AUDIO_LEVEL)) {
              /* Update value */
              emfVolumeLev = queryVal;
              EEPROM.write(AUDIO_LEVEL_ADDR, emfVolumeLev);

#if defined(DFP_DEBUG) || defined(EMF_DEBUG)
              Serial.println(F("Updating EPROM"));
#endif
          }

          /* Check for DFP in bad state and reset */
          /* Seems to be issue with JL AF... chips */
          queryVal = dfpGetStatus();
          if (queryVal == 0x201) {
              /* Player is in play mode, check busy pin and reset if not playing anything. */
              if (digitalRead(DFP_BUSY_PIN)) {

#ifdef NANO
                  digitalWrite(DFP_LOCKUP, 1);  // Set lockup indicator
                  dfpLockupCnt++;
#endif

#ifdef EMF_DEUG
                  Serial.println(F("DFP State: LOCKUP"));
                  Serial.print(F("DFP Lockup Cnt:"));
                  Serial.println(dfpLockupCnt);
                  Serial.println(F("RESET"));
#endif
                  dfpReset();
                  delay(dfpInitDelay);
                  dfpSetEq(DFP_EQ_CLASSIC);
                  dfpSetVolume(emfVolumeLev);
#ifdef NANO
                  digitalWrite(DFP_LOCKUP, 0);  // Set lockup indicator
#endif
              } // end if DFP_BUSY_PIN
          } // end if query
      } // end if EMF_DETECT (Idle)
      emfVolumeSaveTimer = millis();
  } // end if volume save
#endif

  lastSensorValue = sensorValue; 
} // end main loop

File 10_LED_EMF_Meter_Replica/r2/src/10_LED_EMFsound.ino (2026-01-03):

/******************************************************************************************
Supernatural 10 LED EMF Meter Replica

EMF ATTiny Code
Release: 2.1 (Label: EMF / 10r2.1)
Updated serial debug for ATTiny1604
Bug fix for no audio after manual test press
  - remixed 0002_emf low short, now version 2, slightly longer
  - Added in DFPlayer reset check for no audio
  - Fixed audio save limits, now also saved in prog mode

Release: 2.0 (Label: EMF / 10r2)
Initial release for EMF PCB r2
Added mod for volume storage and DFPlayer read


Johnny Electronic
https://github.com/JohnnyElectronic
https://www.youtube.com/@Johnny_Electronic

Description **********************************************
This code uses an AVR device to control a DF Player audio device and drive a VU/LED meter. The EMF level will be determined by
the program/test (Prog) button. When the button is pressed quickly it will cycle through pre-programmed detector senarios. Holding the
button will cause full deflection of the meters. This meter is a prop only and does not have any real EMF detection abilities.

Copyright **********************************************
Copyright 2024 by John Bennett, aka Johnny Electronic.

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
  This program is distributed in the hope that it will be useful, but WITHOUT ANY WARRANTY; 
  without even the implied warranty of MERCHANTABILITY or FITNESS FOR A PARTICULAR PURPOSE. 
  See the GNU General Public License for more details.

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
DFPlayer **********************************************
This code is configured to use the MP3-TF-16P (Blue LED) DF Player. Other DFPlayers may not provide the same response.

DFPlayer - A Mini MP3 Player For Arduino
 <https://www.dfrobot.com/product-1121.html>

 1.Connection and Diagram can be found here
 <https://www.dfrobot.com/wiki/index.php/DFPlayer_Mini_SKU:DFR0299#Connection_Diagram>

 2. The DF files used in this version are a custom creation.
*******************************************************************************************/

#include "DFPlayer.h"
#include <EEPROM.h>

//#define DFP_DEBUG     /* Enables display of received data for query requests to Serial, Nano/ATTINY1604 only */

//#define NANO
#define ATTINY1604
//#define ATTINY85

// Not all pins on the Mega and Mega 2560 boards support change interrupts, 
// so only the following can be used for RX: 10, 11, 12, 13, 14, 15, 50, 51, 52, 53, A8 (62), A9 (63), A10 (64), A11 (65), A12 (66), A13 (67), A14 (68), A15 (69). 

// Nano Pinouts
//DFPlayer.h settings
#ifdef NANO
#define  DFP_RX_PIN    12     // Pin Assigned for serial RX, Connects to DF Player TX, set to -1 if not used - D12 Uno/Nano
#define  DFP_TX_PIN     8     // Pin Assigned for serial TX, Connects to DF Player RX,  - D8 Uno/Nano
#define  DFP_BUSY_PIN   2     // Pin Assigned for busy detection, set to 0 if not used
#define  METER_PIN     11     // PWM output to drive VU meter and LM3914
#define  PROG_PIN      10     // Program/Test Switch Input, Active LOW
#define  PROG_LED_PIN   3     // Indicates running a programmed sequence

// BCD Encoder Switch, Input from BCD encoder switch to select EMF Sequence Number, Active LOW
#define ENC_SW1_PIN   7     // D7, Pin 9, BCD 1
#define ENC_SW2_PIN   6     // D6, Pin 8, BCD 2
#define ENC_SW4_PIN   5     // D5, Pin 7, BCD 4
#define ENC_SW8_PIN   4     // D4, Pin 6, BCD 8

#define RANDOM_AIN    A4    // Used to set a random seed
#endif

// Attny1604 Pinouts - 16MHz Clock
// Use pins 1 and 2 to communicate with DFPlayer Mini
// ---------------------------------------------------------
// ATTny85: AVR_ATtiny85
// Attny804/1604
//                              _____
//                      VDD   1|*    |14  GND
//  (WO4)(nSS)(AIN4) PA4  0~  2|     |13  10~ PA3 (AIN3)(SCK)(EXTCLK)(WO3)
//       (WO5)(AIN5) PA5  1~  3|     |12  9   PA2 (AIN2)(MISO)
//       (DAC)(AIN6) PA6  2   4|     |11  8   PA1 (AIN1)(MOSI)
//            (AIN7) PA7  3   5|     |10  11  PA0 (AIN0)(nRESET/UPDI)
// (WO*)(RXD)(TOSC1) PB3  4   6|     |9   7~  PB0 (AIN11)(SCL)(WO0)
// (WO2)(TXD)(TOSC2) PB2  5~  7|_____|8   6~  PB1 (AIN10)(SDA)(WO1)
// 
// LED_BUILTIN    (PIN_PA7, 3)
// WO- Waveform Output (Timers, PWM ~)
// External interrupt on all general purpose pins
// 

#ifdef ATTINY1604
#define DFP_BUSY_PIN  3     // Pin 5, Assigned for busy detection
#define DFP_TX_PIN    1     // Pin 3, Assigned for serial TX, Connects to DF Player RX (Pin 2)
#define DFP_RX_PIN    2     // Pin 4, Assigned for serial RX, Connects to DF Player TX (Pin 3), set to -1 if not used
#define PROG_PIN      8     // Pin 11, Assigned for Program/Test Switch Input 
#define METER_PIN     10    // Pin 13, Assigned for PWM output to drive VU meter
#define PROG_LED_PIN  9     // Pin 12, Indicates running a programmed sequence
// BCD Encoder Switch, Input from BCD encoder switch to select EMF Sequence Number, Active Low
#define ENC_SW1_PIN   7     // D7, Pin 9, BCD 1
#define ENC_SW2_PIN   5     // D5, Pin 7, BCD 2
#define ENC_SW4_PIN   6     // D6, Pin 8, BCD 4
#define ENC_SW8_PIN   4     // D4, Pin 6, BCD 8

#define RANDOM_AIN    A4    // Pin 2, Used to set a random seed, used for Serial Monitor when active

//Serial Monitor Debug
#define SER_TX_PIN    0     // Pin 2, Assigned for serial TX, Connects to Serial Monitor RX
#define SER_RX_PIN    -1    // Pin 4, Assigned for serial RX, Connects to Serial Monitor TX, Set to -1 if not used
#endif

// ATtiny85 Pinouts
// Use pins 2 and 3 to communicate with DFPlayer Mini
// ---------------------------------------------------------
// ATTny85: AVR_ATtiny85
//                          _____
// (Reset)  (A0) PB5  5   1|*    |8  VCC
// (Xtal)   (A3) PB3  3   2|     |7  2   PB2 (A1)(INT0)(SCK)
// (Xtal)   (A2) PB4  4   3|     |6  1~  PB1     (MISO)
//                   GND  4|_____|5  0~  PB0     (MOSI)
// 
// ---------------------------------------------------------
/* DFP_BUSY_PIN     - D3, Pin 2
 * DFP_TX_PIN       - D4, Pin 3
 * progSwPin        - D2, Pin 7
 * meterPin         - D0, Pin 5
 * progLEDpin       - D1, pin 6
 */
#ifdef ATTINY85
#define DFP_BUSY_PIN  3     // ATTiny85 PB3, pin 2, pin Assigned for busy detection
#define DFP_TX_PIN    4     // Pin Assigned for serial TX, Connects to DF Player RX, ATTiny85 PB4, pin 3
#define DFP_RX_PIN   -1     // Pin Assigned for serial RX, set to -1 if not used
#define PROG_PIN      2     // D2, pin 7, Program/Test Switch Input 
#define METER_PIN     0     // D0, Pin 5, PWM output to drive VU meter
#define PROG_LED_PIN  1     // D1, Pin 6, Indicates running a programmed sequence
#endif

// Program (PROG/TEST) button
// 1 - Press and hold PROG/TEST button and the meter will deflect full while button is held
// 2 - Quickly press and release PROG/TEST button will cycle through the available programmed senarios.
//     Starts with program 1 and cycles though to the nth program and loops back to 1. The PROG_LED will
//     indicate when a selected program is running.
//
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

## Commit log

2025-05-12 Initial release
    [9v_Battery_Holder_Single_3_5mm hole.3mf, AA_Battery_Pack_Holder_10_LED_EMF.3mf, AA_Battery_Pack_Holder_10_LED_EMF.stl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]
2025-05-12 Added assembled images
2025-05-12 Changed image size, PCB
2025-07-28 Created EMF Meter doc (R1.2) that contains both the Build document and the User Guide. Updated DF player types in the BOM
2025-07-29 BOM updates and clarifications
2025-08-27 Set up for R2 release
    [AA_Battery_Pack_Holder_10_LED_EMF.stl, AA_Battery_Pack_Holder_EMF.3mf, AA_Battery_Pack_Holder_EMF.stl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]
2025-08-27 Added additional files
    [AA_Battery_Pack_Holder_10_LED_EMF.3mf]
2025-08-27 Updated purchasing sections and removed moved eD folder
    [EMF_P_Clip_5mm_dia.3mf, EMF_P_Clip_5mm_dia.stl, EMF_P_Clip_6mm_dia.3mf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]
2025-09-02 Updated src code with 1.1. Added PCB modifications to build document.
2025-09-03 Added wire options to BOM
2025-09-09 Update main readme for 10 LED meter
2025-09-10 Update README.md
    Added PCBWay link and adjusted image sizes
2025-09-20 Added EMF sound file and 3D files
    [AA_Battery_Pack_Holder_10_LED.3mf, AA_Battery_Pack_Holder_EMF.3mf]
2025-09-20 Updated board BOM
2025-11-29 Added DFPlayer source code folder Works with EMF and 10 LED EMF Meter Replicas
2025-11-29 Updated to release 1.4 of assembly and user manual guides
2025-11-30 Added default code to switch statement.
2025-12-02 Updated BOM
2025-12-12 Updated for release of EMF meter version r2
    [9v_Battery_Holder.3mf, 9v_Battery_Holder_Single_3_5mm hole.3mf, AA_Bat_Holder_EMF_r2.3mf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]
2025-12-14 New lever for SW2 rotary switch
    [Potentiometer Lever.3mf]
2025-12-17 Updated back/side images to show rotary switch lever
2026-01-02 Updated 10 LED EMF changes for build R2.1, doc rev 2.2
2026-04-12 Switch lever for EMF r2 PCB
    [Rotary Switch Lever.3mf]
2026-04-12 Changed file name
    [Potentiometer Lever.3mf]
2026-04-12 Added EMF R2 meter Base updates
    [EMF_Meter_Base_all versions.3mf, EMF_Meter_Base_r1.3mf, EMF_Meter_Base_r1.stl]
2026-04-13 Updates and clean up of r2 code base. Has debug option and reset for DFplayer lockup Cleaned up debug print statements
    [EMFsound_r2.ino]

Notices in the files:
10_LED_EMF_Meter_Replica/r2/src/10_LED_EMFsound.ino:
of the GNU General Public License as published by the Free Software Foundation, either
